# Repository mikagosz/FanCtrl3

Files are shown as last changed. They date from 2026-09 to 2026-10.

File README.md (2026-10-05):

<p align="center">
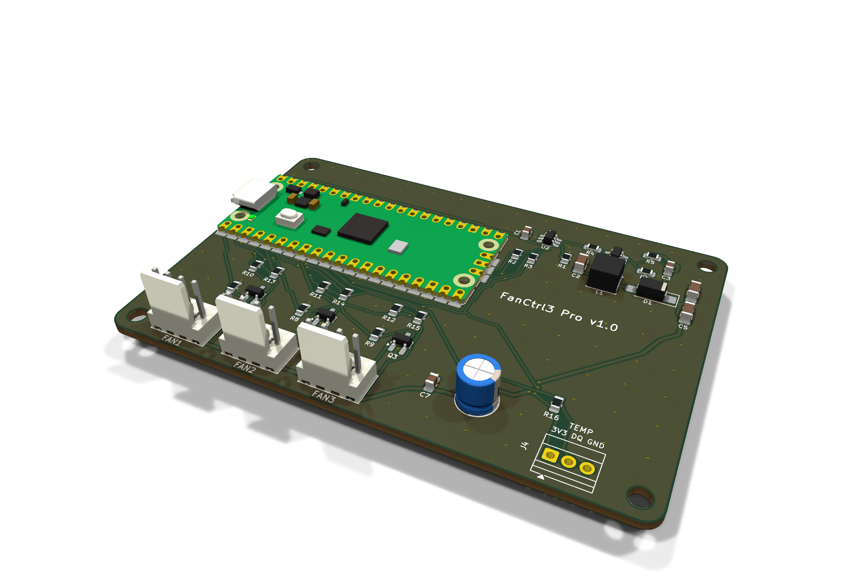
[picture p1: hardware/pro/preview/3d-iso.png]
FanCtrl3 Pro PCB, 3D render: Raspberry Pi Pico, three 4-pin fan headers, a temperature probe terminal and the on-board 12 V boost converter
  
</p>

## FanCtrl3

**A USB-powered controller for three 4-pin PWM fans, driven by the CPU temperature
of a Proxmox VE host.**

One USB cable to the host is all it needs — power, control and fan speed readings
all go over it. The fan curve runs **inside the controller**, so a host reboot, a
crashed service or a pulled cable never leaves the fans stopped.









Designed for small home servers and mini PCs running Proxmox: the machine sits in a
closed cabinet, its own fan is not enough for the cabinet, and a set of quiet 120 mm
fans should spin up only when the server actually works.

> [!NOTE]
> FanCtrl3 is a hobby project, built in spare time. Updates may not come often —
> but ideas, questions and build reports are always welcome (see
> [Contact and contributions](#contact-and-contributions)).

---

## Project status

> [!WARNING]
> **FanCtrl3 has not been tested on real hardware yet.** Hardware testing is coming
> soon; this section will be updated with the results. Until the first boards have
> run for a while, treat this as a reviewed design, not a proven product.

### Verified without hardware

| Area | How | Result |
|---|---|---|
| Schematics | KiCad ERC, both variants | 0 errors, 0 warnings |
| Pro PCB | KiCad DRC with schematic parity | 0 violations, 0 unconnected pads, 0 parity issues |
| Lite perfboard | the generator's own checker | every net connected, no hole shared by two nets, no wire through a foreign pad, no overlapping parts |
| Enclosure | intersection of the enclosure with the component bodies | 0 collisions, both variants |
| Control logic | 22 unit tests, run under CPython **and** MicroPython | all pass |
| Firmware `main.py` | runs under the MicroPython unix port on stubbed hardware: replies, 25 kHz inverted PWM, watchdog; `SERVICE` and service mode; `SAVE` success and failure (12 checks) | all pass |
| Host daemon and CLI | 10 unit tests (Intel and AMD sensors, several CPU packages, CLI errors, a silent socket client) and 13 end-to-end tests against a simulated controller: sensor selection, curve, `status`, `send`, `calibrate` (incl. a dead fan and failsafe), clean stop, restart without a temperature, crash → failsafe | all pass |

Every push and pull request runs these tests on GitHub Actions.

### Not tested yet

- Anything on a real board: soldering, the 12 V rail, the current limiter and its
  `FAULT` signal, real fan speeds from the tachometers, the DS18B20 probe, the LED,
  the watchdog, USB behaviour with and without a host.
- Power drawn from a real USB port with three fans at 100 %.
- The udev rule on a real Pico (`2e8a:0005` is MicroPython's default ID).
- Printing and fitting the enclosure; the Lite mounting-hole positions.

### Known issues

- AMD support (`k10temp`, `zenpower`) is tested only against simulated sensors so
  far — a report from a real AMD host is welcome.
- `tests/test_main_smoke.sh` depends on timing and can fail on a heavily loaded
  machine; run it again before looking for a bug.

## Features

- **Three 4-pin PWM fans**, 25 kHz PWM and tachometer reading on every channel.
- **Powered from USB only.** An on-board step-up makes the 12 V for the fans; a
  TI TPS2553 current-limited switch limits the fan side to 465–570 mA — the
  budget of a USB 2.0 port — and reports an overload to the controller.
- **Curve in the controller, temperature from the host.** A small daemon on the
  Proxmox host sends the CPU package temperature (Intel or AMD) every 5 seconds; the
  controller applies a curve with hysteresis and ramping.
- **Safe by default.** No temperature for 30 s → fans at 100 %. A dead
  microcontroller → the output transistors switch off → fans at 100 %. A clean host
  shutdown → fans rest at 20 % instead of alarming.
- **Ambient probe.** A DS18B20 on a cable measures the air in the cabinet and raises
  the fans on its own above 40 °C (60 %) and 45 °C (100 %).
- **Stall detection** per fan, per-fan minimum duty and a `calibrate` command that
  measures it.
- **Two variants, one firmware** — see below.
- **Host side needs nothing but Python 3's standard library**, a udev rule and a
  systemd unit.

## Two variants

| | **FanCtrl3 Lite** | **FanCtrl3 Pro** |
|---|---|---|
| Build | modules on a 72 × 47 mm perfboard (SCI PC-3) | custom 2-layer PCB, 90 × 60 mm |
| Soldering | through-hole only (plus one SOT-23-6 on an adapter) | 0805/1206 and SOT-23 by hand, no QFN |
| 12 V | Pololu U3V16F12 module | TI LM27313 boost on the board (12.4 V) |
| PWM output | BC547B, open collector | 2N7002, open drain |
| Current limit | TPS2553 on a SparkFun SOT-23 → DIP adapter | TPS2553 on the board |
| Pico | in sockets, removable | soldered flat |
| Build guide | [docs/build-lite.md](docs/build-lite.md) | [docs/build-pro.md](docs/build-pro.md) |

Both use the same pinout and run the same firmware.

<table>
  <tr>
    <td align="center">Lite perfboard drawing: component side and mirrored solder side with every wire<br><sub>Lite — perfboard wiring drawing</sub></td>
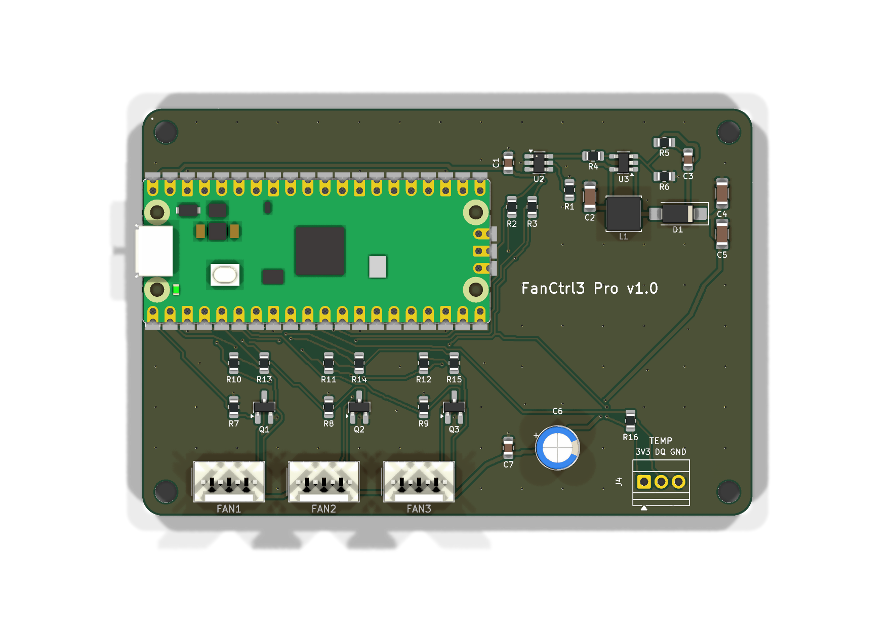
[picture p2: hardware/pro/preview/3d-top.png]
Pro PCB, 3D render from the top
    <td align="center"><br><sub>Pro — PCB, top</sub></td>
  </tr>
  <tr>
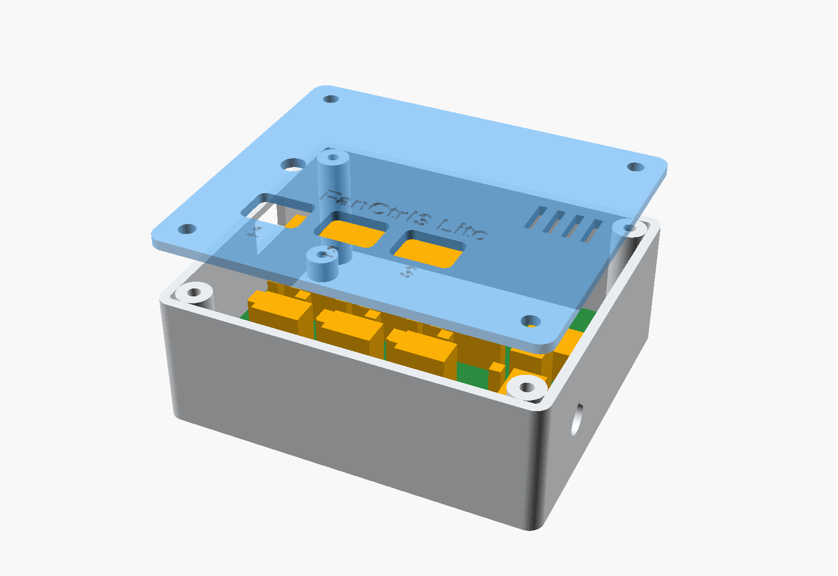
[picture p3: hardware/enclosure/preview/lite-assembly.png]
Lite enclosure with the board inside, preview
    <td align="center"><br><sub>Lite — enclosure</sub></td>
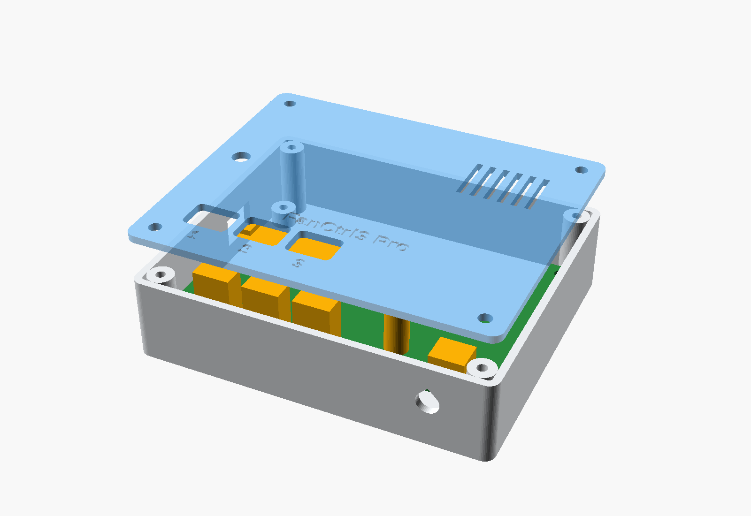
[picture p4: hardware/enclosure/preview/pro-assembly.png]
Pro enclosure with the board inside, preview
    <td align="center"><br><sub>Pro — enclosure</sub></td>
  </tr>
</table>

## How it works

```
 Proxmox host                                 FanCtrl3
┌────────────────────────┐   USB cable    ┌──────────────────────────────────────┐
│ CPU temp ─► fanctl     │  power + data  │ Pico: curve, hysteresis, failsafe    │
│             daemon ────┼───────────────►│  ├─ PWM ×3 ──► open collector/drain  │
│  TEMP 54.0 every 5 s   │◄───────────────│  ├─ tach ×3 ◄── fans                 │
│  STATUS, alarms        │                │  └─ DS18B20 ◄── ambient probe        │
└────────────────────────┘                │                                      │
                                          │ VBUS ─► TPS2553 ─► 12V boost ─► fans │
                                          │         (≈0.5 A)                     │
                                          └──────────────────────────────────────┘
```

The link is plain text over USB CDC — `TEMP 54.0`, `STATUS`, `SET 1 40` — so it can
be driven by hand from any terminal. Full protocol: [docs/firmware.md](docs/firmware.md).

## Power budget

The whole controller lives on one USB 2.0 port, which is allowed to supply
**500 mA**. The design is sized for three low-power 120 mm PWM fans rated at up
to **0.6 W each** (for example Noctua NF-P12 redux-1300 PWM):

3 × 0.6 W = 1.8 W at 12 V → ÷ 0.85 converter efficiency + ≈ 0.15 W for the Pico
≈ **0.45 A from the port**.

> [!CAUTION]
> Fans rated above 0.6 W each will not fit this budget. The TPS2553 limits the fan
> side to 465–570 mA and reports `FAULT`, but the fans will not reach full speed.
> Check the rated **input power** of your fans before you build.

## Getting started

1. **Pick a variant** and order the parts — [docs/bill-of-materials.md](docs/bill-of-materials.md).
2. **Build the board** — [Lite](docs/build-lite.md) or [Pro](docs/build-pro.md).
3. **Print the enclosure** — [docs/enclosure.md](docs/enclosure.md).
4. **Flash the firmware** — [docs/firmware.md](docs/firmware.md):
   MicroPython for `RPI_PICO`, then `firmware/flash.sh`.
5. **Install the host side on Proxmox** — [docs/host-proxmox.md](docs/host-proxmox.md):
   ```bash
   sh host/install.sh        # as root on the Proxmox host
   fanctl status
   fanctl calibrate          # finds the lowest duty each fan still spins at
   ```

## Repository layout

| Path | What is inside |
|---|---|
| [`hardware/tools/`](hardware/tools/) | generators — the design lives in code: [`design_pro.py`](hardware/tools/design_pro.py) and [`design_lite.py`](hardware/tools/design_lite.py) are the single source of truth |
| [`hardware/pro/`](hardware/pro/) | KiCad project of the Pro PCB, schematic PDF, [`fabrication/`](hardware/pro/fabrication/) Gerbers + drill ZIP and BOM, [`preview/`](hardware/pro/preview/) 3D renders |
| [`hardware/lite/`](hardware/lite/) | Lite schematic (KiCad + PDF), perfboard drawing (SVG) and wiring table |
| [`hardware/enclosure/`](hardware/enclosure/) | parametric OpenSCAD enclosure and ready STL files for both variants |
| [`firmware/`](firmware/) | MicroPython for the Pico: [`logic.py`](firmware/logic.py) (no hardware, testable) and [`main.py`](firmware/main.py) (pins) |
| [`host/`](host/) | `fanctl` daemon and CLI, udev rule, systemd unit, installer |
| [`sim/`](sim/) | the controller on a pseudo-terminal, for testing the host side without hardware |
| [`tests/`](tests/) | everything that runs without hardware: [`tests/run_all.sh`](tests/run_all.sh) |
| [`docs/`](docs/) | documentation |

## Documentation

- [Hardware design](docs/hardware.md) — circuit description, pinout, design decisions
- [Bill of materials](docs/bill-of-materials.md) — both variants, with suggested shop links
- [Building FanCtrl3 Lite](docs/build-lite.md) — perfboard assembly
- [Building FanCtrl3 Pro](docs/build-pro.md) — ordering the PCB and hand soldering
- [Enclosure](docs/enclosure.md) — printing and assembly
- [Firmware](docs/firmware.md) — flashing, control behaviour, serial protocol
- [Host software on Proxmox](docs/host-proxmox.md) — installation and `fanctl`
- [Development](docs/development.md) — regenerating the outputs, running the tests

## Contact and contributions

Ideas, improvements, a better circuit, a build report or a question — all welcome.
Open an issue on this repository or write to **support@fractal8.eu**. See
[CONTRIBUTING.md](CONTRIBUTING.md).

## Support the project

FanCtrl3 is built in spare time. If it is useful to you, you can support its
development through **[GitHub Sponsors](https://github.com/sponsors/mikagosz)** —
it helps pay for parts and prototype boards.

## Licence

MIT — see [LICENSE](LICENSE). This covers the hardware design files, the firmware
and the host software.

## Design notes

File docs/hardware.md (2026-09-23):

# Hardware design

FanCtrl3 comes in two variants built from the same circuit blocks: **Lite**
(ready-made modules on a perfboard) and **Pro** (everything on a custom PCB). They
share the pinout, so one firmware runs on both.

> [!NOTE]
> The hardware has not been tested yet — hardware testing is coming soon. The
> schematics pass ERC, the Pro PCB passes DRC and schematic parity, and the Lite
> perfboard layout passes its own connectivity check. See the
> [project status](../README.md#project-status).

Schematics: [Pro (PDF)](../hardware/pro/FanCtrl3-Pro-schematic.pdf) ·
[Lite (PDF)](../hardware/lite/FanCtrl3-Lite-schematic.pdf) — also as SVG in
[`docs/images/`](images/).

## Block diagram

```
USB VBUS (5 V) ──┬──────────────────────────────► Pico VBUS (the Pico makes its own 3.3 V)
                 │
                 └─► TPS2553 ─► +5V_FAN ─► 5 V → 12 V boost ─► +12V ─► fan headers J1–J3 (pin 2)
                     │    │
          FAULT → GP7    EN ← GP8 (pulled up: on by default)

Pico GP0/GP2/GP4 ─► NPN / N-MOSFET ─► fan PWM (pin 4, open collector / open drain)
Pico GP1/GP3/GP5 ◄── 10 kΩ ◄──┬── fan tach (pin 3)
                              └── 4.7 kΩ to 3.3 V
Pico GP6 ◄──► DS18B20 probe (1-Wire, 4.7 kΩ pull-up) on a 3-pole screw terminal
```

## Pinout (both variants)

| Pico pin | GPIO | Function |
|---|---|---|
| 1 | GP0 | fan 1 PWM |
| 2 | GP1 | fan 1 tach |
| 4 | GP2 | fan 2 PWM |
| 5 | GP3 | fan 2 tach |
| 6 | GP4 | fan 3 PWM |
| 7 | GP5 | fan 3 tach |
| 9 | GP6 | DS18B20 data (1-Wire) |
| 10 | GP7 | TPS2553 `FAULT` (open drain, active low, 10 kΩ pull-up) |
| 11 | GP8 | TPS2553 `EN` (active high, pulled up) |
| 36 | 3V3 | tach pull-ups, 1-Wire, limiter pull-ups |
| 40 | VBUS | 5 V from the host |
| — | GP25 | on-board LED: status |

Fan header (standard 4-pin PC fan, Molex KK 254): **1** GND · **2** +12 V ·
**3** tach · **4** PWM. The DS18B20 terminal: **1** 3.3 V (red) · **2** DQ (yellow) ·
**3** GND (black).

## Power

### Budget

The controller takes everything from one USB port. A USB 2.0 device — the Pico is
one — may draw **500 mA**. FanCtrl3 is sized for three fans of up to **0.6 W** each:

| | |
|---|---|
| Fans at 100 % | 3 × 0.6 W = 1.8 W at 12 V |
| From 5 V, 85 % converter efficiency | ≈ 2.1 W |
| Pico | ≈ 0.15 W |
| **Total from the port** | **≈ 0.45 A** |

Heavier fans do not fit: the current limiter will hold the fan side at its limit
and report `FAULT`, and the fans will not reach full speed.

### Current limiter — TPS2553

The fan side sits behind a **TI TPS2553** current-limited power switch. The Pico
itself stays on raw VBUS, so it keeps running and can report the problem when the
fans are shorted or overloaded.

- **RILIM = 51 kΩ** → current limit **465–570 mA** (TI datasheet, equation 1).
- **`FAULT`** (open drain, 10 kΩ pull-up to 3.3 V) goes to GP7. The firmware reports
  `ALARM FAULT` / `INFO FAULT OK`. The TPS2553 filters short events such as inrush
  at start-up.
- **`EN`** (active high) is pulled up to 3.3 V, so the fans are powered even
  before the firmware runs and when the Pico is dead. GP8 drives it high.
- 100 nF at the `IN` pin.

On **Pro** the TPS2553 is on the board (SOT-23-6). On **Lite** it sits on a
**SparkFun BOB-00717** SOT-23 → DIP-6 adapter (8.6 × 11.7 mm, rows 7.62 mm apart),
together with C3 and the flat-mounted resistors R14–R16, **under** the Pico — the Pico
stands 11 mm above the perfboard in its sockets and the adapter is about 6 mm tall.

### 12 V

| | Lite | Pro |
|---|---|---|
| Converter | **Pololu U3V16F12** module, fixed 12 V ± 4 % | **TI LM27313** boost, SOT-23-5 |
| Output | 12 V | 12.4 V (divider 91 kΩ / 10 kΩ: 1.23 V × (1 + 91/10)) |
| Parts | 47 µF at the module input (Pololu recommends ≥ 33 µF), 100 µF on the 12 V rail | 10 µH inductor, SS14 Schottky diode, 220 pF feed-forward across the top divider resistor, 2 × 10 µF + 100 µF + 100 nF on the output, 10 µF at the input; `SHDN` pulled up (51 kΩ) |
| Basis | module datasheet | TI's typical 5 V → 12 V / 250 mA application |

A fixed output was chosen on purpose: no trimmer that could drift or be set wrong.
12.4 V is within the normal tolerance of 12 V fans.

## Fan channels

### PWM output

4-pin fans pull their PWM input up internally and expect an **open-collector /
open-drain** driver at **25 kHz**. Pulling the line low slows the fan down.

| | Lite | Pro |
|---|---|---|
| Transistor | BC547B (NPN, TO-92) | 2N7002 (N-MOSFET, SOT-23) |
| Drive | GPIO → 4.7 kΩ → base, 10 kΩ base to GND | GPIO → gate, 100 kΩ gate to GND |

Because the transistor pulls the line low, the logic is **inverted**: GPIO high →
transistor on → fan slower. The firmware takes care of it.

**Fail-safe by construction:** when the Pico is dead, unplugged from its socket or
still booting, the pull-down resistor keeps the transistor off, the fan pulls its
own PWM line high, and the fan runs at **100 %**. The same applies at power-up —
all three fans start at full speed until the firmware takes over.

A BC547 is used on Lite rather than a 2N7000 because a 2N7000 is only marginally
on with 3.3 V at the gate.

### Tachometer

The fan's tach output is an open collector, 2 pulses per revolution. It is pulled
up to **3.3 V with 4.7 kΩ on the fan side** and then goes through **10 kΩ in
series** to the GPIO. The series resistor protects the Pico if a fan (or a wrong
cable) drives the tach line to 12 V. The order matters: with the 10 kΩ first and
the pull-up at the GPIO, the low level would not go below about 2.2 V.

## Ambient temperature

A **DS18B20 probe on a cable** (waterproof version) sticks out of the enclosure
and measures the air in the cabinet, not the heat of the board. It connects to a
3-pole screw terminal — no crimping. 4.7 kΩ pull-up on DQ.

The controller uses it on its own, whatever the host says: from **40 °C** the fans
run at least **60 %**, from **45 °C** at **100 %**.

## Layout notes

### Pro PCB

- 2 layers, 90 × 60 mm, 1.6 mm, four M3 mounting holes in the corners.
- Smallest track 0.25 mm, vias 0.3/0.6 mm, smallest hole 0.3 mm — standard
  capabilities of common low-cost PCB fabs.
- Hand-solderable footprints only: 0805/1206 with "HandSolder" pads, SOT-23, SMA,
  no parts with pads underneath.
- The Pico is soldered flat by its castellated edge; its micro-USB socket overhangs
  the board edge by about 1 mm for the enclosure opening.
- Ground pour on both layers. Power tracks (VBUS, the limited 5 V, the converter
  switch node and 12 V) are 0.4–0.6 mm wide, signals 0.25 mm.

### Lite perfboard

- SCI PC-3: 25 × 15 holes on 2.54 mm, 72 × 47 mm, single-sided, the four corner
  positions are mounting holes (371 holes).
- The Pico sits in two 20-pin sockets along rows B and I, USB to the left. Fan
  headers along the bottom edge, at least 15.24 mm apart so the lid openings do not
  merge. The probe terminal and the Pololu module are on the right.
- Ground is a bare rail along row O. Everything else is bare wire on the solder
  side, plus 15 insulated wires where a bare route would be too long or impossible
  (3.3 V and 12 V are always insulated).
- The layout, the wiring and the checks are generated — see
  [development.md](development.md).
- Wiring table: [`hardware/lite/FanCtrl3-Lite-wiring.md`](../hardware/lite/FanCtrl3-Lite-wiring.md).

## Known limitations

- **Not tested on hardware yet.** Footprints of the Molex header and the screw
  terminal were checked against drawings; the SparkFun adapter dimensions come from
  the SparkFun product page; nothing has been built yet.
- The fans start at 100 % when USB is plugged in, before the firmware runs. That
  is intentional (fail-safe) and stays within the current limit, but it is audible.
- Only fans up to about 0.6 W each fit the USB power budget.

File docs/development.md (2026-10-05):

# Development

The hardware of FanCtrl3 is **generated from code**. Each variant has one design
file that is the single source of truth; KiCad files, the perfboard drawing, the
wiring table, the enclosure geometry and the fabrication outputs are all derived
from it. Edit the design file, run the build script, commit the results.

## Tools

| Tool | Version used | Needed for |
|---|---|---|
| Python | 3.9 or newer (developed on 3.14) | generators, host daemon, tests |
| KiCad | 10 | schematics, PCB, ERC/DRC, Gerbers, renders |
| OpenSCAD | 2024 or newer, Manifold backend (developed on 2026.06) | enclosure |
| MicroPython (unix port) | 1.2x (developed on 1.29) | running the firmware tests |
| mpremote | any recent | copying the firmware to the Pico |
| bash | 3.2 or newer (macOS's built-in one is enough) | the build and test scripts (`*.sh`, except `host/install.sh`, which is POSIX sh) |

The scripts use the default macOS install location of KiCad. Elsewhere, point them
at your install:

```bash
export KICAD_CLI=/usr/bin/kicad-cli
export KICAD_PYTHON=/usr/bin/python3          # a Python that can `import pcbnew`
export KICAD_SHARE=/usr/share/kicad           # holds symbols/ and footprints/
```

## Hardware

### Pro — `hardware/tools/design_pro.py`

```bash
hardware/tools/build_pro.sh    # schematic -> ERC -> place -> geom -> route -> finish -> DRC
hardware/tools/export_pro.sh   # Gerbers + drill -> ZIP, BOM CSV, schematic PDF
```

- `gen_sch.py` writes the schematic: every pin gets a short stub with a net label or
  power symbol, so every connection is explicit.
- `gen_pcb.py place` places the footprints and the silkscreen (inside KiCad's
  Python), `gen_pcb.py geom` exports the pad geometry, `router.py` routes the tracks,
  and `gen_pcb.py finish` adds them to the board with GND stitching vias and fills
  the ground zones.
- DRC runs with `--schematic-parity`: the board has to match the schematic.
- The router is not deterministic — each run gives slightly different tracks, each
  passing DRC. **Run `export_pro.sh` right after every `build_pro.sh`.**

### Lite — `hardware/tools/design_lite.py`

```bash
hardware/tools/build_lite.sh   # layout search + routing + checks, SVG, wiring table, enclosure geometry, schematic, ERC, PDF
```

`gen_lite.py` tries every combination of fan-channel columns and limiter
positions (280 placements), routes each with a few random net orders, then gives
the five best many more orders. Bare wire runs hole to hole on the solder side and
never shares a hole with another net; what cannot be routed that way within a
detour limit becomes an insulated wire. The layout with the fewest signal wires,
then the shortest insulated wire, wins. A full run takes about two minutes and
gives the same result every time.

The checker rejects a layout if any net is not connected, a hole carries two nets,
a wire passes a foreign pad, a part sticks out of the board, part bodies overlap,
or a part under the Pico covers its sockets.

Environment variables for quick experiments: `LITE_TRIES_FIRST` (default 20),
`LITE_KEEP` (5), `LITE_TRIES` (120).

Translations: when a file `<lang>/lang_<lang>.py` exists at the repository root,
`build_lite.sh` also writes the drawing and the wiring table in that language into
the same folder. Such local folders are not tracked.

### Enclosure

```bash
hardware/tools/build_enclosure.sh   # 4 STL files, collision check, previews
```

Run `build_lite.sh` first when the Lite layout changed — it writes
`hardware/enclosure/FanCtrl3-lite-geometry.scad`, which the enclosure reads.

## Firmware and host

```bash
tests/run_all.sh
```

| Test | What it covers |
|---|---|
| `tests/test_logic.py` | the control logic, under CPython **and** MicroPython (same file, plain asserts): curve, hysteresis, ramps, stale temperature, BYE/rest, minimum duty, ambient override, stall alarm, FAULT edge, manual mode, protocol errors, config merge |
| `tests/test_main_smoke.sh` | the real `firmware/main.py` under the MicroPython unix port with a stub `machine` module ([`tests/stubs/machine.py`](../tests/stubs/machine.py)): replies to commands, 25 kHz PWM, inverted output, 8 s watchdog |
| `tests/test_e2e.py` | host daemon + CLI against [`sim/pico_sim.py`](../sim/pico_sim.py), a simulated controller on a pseudo-terminal with pretend fans: waiting for the device, picking the right hwmon sensor, curve, `status`, `send`, `calibrate`, clean stop → rest, crash → failsafe |

The simulator is also handy on its own for trying the host side:

```bash
python3 sim/pico_sim.py --link /tmp/fanctl
fanctl --device /tmp/fanctl status
```

## Conventions

- One design file per variant; generated files are committed so that people can
  use them without running anything, but never edited by hand.
- Firmware logic without hardware in `logic.py`, pins and timers in `main.py` —
  everything that can be tested off the board lives in `logic.py`.
- The host side uses the Python standard library only.

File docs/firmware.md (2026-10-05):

# FanCtrl3 firmware

FanCtrl3 drives three 4-pin PWM fans from a Raspberry Pi Pico running MicroPython.
The controller is powered over USB and runs the fan curve itself. The host only reports
the CPU temperature over the same USB cable (see [host-proxmox.md](host-proxmox.md)).

> [!NOTE]
> **Status:** the hardware has not been tested yet. The firmware logic and the host daemon
> pass automated tests against a simulator. Hardware testing is coming soon.

## Contents

- [Firmware files](#firmware-files)
- [Installing MicroPython](#installing-micropython)
- [Copying the firmware](#copying-the-firmware)
- [Service access](#service-access)
- [Pinout](#pinout)
- [Control behaviour](#control-behaviour)
- [Serial protocol](#serial-protocol)
- [The STAT line](#the-stat-line)
- [Unsolicited messages](#unsolicited-messages)
- [Configuration and persistence](#configuration-and-persistence)
- [Status LED](#status-led)
- [Watchdog and error handling](#watchdog-and-error-handling)
- [Simulator and tests](#simulator-and-tests)

## Firmware files

| File | Purpose |
|---|---|
| [`firmware/logic.py`](../firmware/logic.py) | All control decisions: modes, fan curve, hysteresis, ramps, alarms, the command protocol and the configuration defaults. It does not access any hardware and runs under both MicroPython and CPython. |
| [`firmware/main.py`](../firmware/main.py) | Hardware layer for the Pico (MicroPython `rp2` port): PWM outputs, tachometer inputs, DS18B20 ambient probe, power-switch fault input, LED, watchdog, USB serial I/O and the configuration file. |
| [`firmware/flash.sh`](../firmware/flash.sh) | Copies `logic.py` and `main.py` onto a Pico that already runs MicroPython. |

The firmware version is `VERSION` in `logic.py`; `VER` reports it. It follows the project version in [CHANGELOG.md](../CHANGELOG.md).

## Installing MicroPython

The firmware needs the standard MicroPython build for the Raspberry Pi Pico.

1. Download the MicroPython UF2 file for the **`RPI_PICO`** board from micropython.org.
2. Hold down the **BOOTSEL** button on the Pico and connect it to your computer over USB.
   Release the button once it is connected.
3. The Pico appears as a USB drive. Copy the UF2 file onto it. The Pico reboots into
   MicroPython when the copy completes.

## Copying the firmware

[`firmware/flash.sh`](../firmware/flash.sh) uses `mpremote` to copy the two firmware files
to the root of the Pico's filesystem and reset the board. It runs the following command
from the `firmware/` directory:

```sh
mpremote connect auto cp logic.py :logic.py + cp main.py :main.py + reset
```

Requirements on the computer used for flashing:

- `mpremote`, installed with `pipx install mpremote` (or `pip install --user mpremote`).
- `bash`, which `flash.sh` runs in (on macOS the built-in one is enough).

To flash a Pico that runs a fresh MicroPython install, connect it and run:

```sh
./firmware/flash.sh
```

After the reset, `main.py` starts automatically and the controller begins in **start** mode.

To update a controller that is already running FanCtrl3, you must first get past its
Ctrl-C protection. See [Service access](#service-access).

> [!IMPORTANT]
> If the controller is connected to a host running the `fanctl` daemon, stop the daemon
> first (`systemctl stop fanctl`). The daemon holds the serial port open. Stopping it
> sends `BYE`, so the controller switches to rest duty.

## Service access

After the service window closes, the firmware ignores Ctrl-C (`micropython.kbd_intr(-1)`).
Without this protection, one stray byte on the serial line could stop the program and
leave the fans without control. You can reach the MicroPython REPL (and therefore
`mpremote`) in two ways:

| Method | How it works |
|---|---|
| **Service window** | For the first **3000 ms** after power-up (`SERVICE_WINDOW_MS`), Ctrl-C still works. During this window the firmware prints the banner `FanCtrl3 <version> start` and waits. The fans run at the start duty. The control loop and the watchdog have not started yet, and commands are not processed. Run `flash.sh` (or any `mpremote` command) right after you connect or reset the board. |
| **`SERVICE` command** | The controller replies `OK SERVICE`, sets all three fans to 100 %, prints `SERVICE: resetting into service mode`, leaves a flag file (`fanctrl3.service`) and resets. The next boot finds the flag, removes it, keeps the fans at 100 %, prints `FanCtrl3 <version> service mode: REPL, fans at 100%, reset to resume` and stays at the MicroPython REPL — **without starting the watchdog**. Send it with `fanctl send SERVICE` from the host. |

The reset is deliberate: the RP2040 watchdog cannot be stopped once it runs, so the
firmware never drops to the REPL from the running control loop. Service mode lasts
until the next reset or power-cycle; `flash.sh` resets the board when it finishes, and
the board then starts normally.

## Pinout

The pinout is the same on the Pro and Lite boards.

| Pico pin | Direction | Function |
|---|---|---|
| GP0 | Output | Fan 1 PWM |
| GP1 | Input, pull-up | Fan 1 tachometer |
| GP2 | Output | Fan 2 PWM |
| GP3 | Input, pull-up | Fan 2 tachometer |
| GP4 | Output | Fan 3 PWM |
| GP5 | Input, pull-up | Fan 3 tachometer |
| GP6 | 1-Wire | DS18B20 ambient temperature probe |
| GP7 | Input, pull-up | TPS2553 `FAULT`, active low (on the Lite board the TPS2553 sits on an adapter) |
| GP8 | Output, driven high | TPS2553 `EN`. Driven high so the fans are powered; the board also pulls it up. |
| `LED` | Output | On-board status LED |

**PWM outputs.** The PWM frequency is 25 kHz. Each output drives an open-collector /
open-drain stage, so the logic is inverted: a high pin turns the transistor on, pulls the
fan's PWM line low and slows the fan. The firmware writes
`duty_u16 = (100 − duty%) × 65535 / 100`. At initialisation every pin is low (transistor
off), so the fans run at full speed until the controller applies the start duty.

**Tachometer inputs.** The firmware counts falling edges in interrupt handlers and
converts them to rpm once per control step, assuming **2 pulses per revolution**:
`rpm = pulses × 60 / 2 / elapsed seconds`.

**Ambient probe.** The DS18B20 is read without blocking. The firmware starts a conversion
and reads the result on a later pass, at least 800 ms after the start. It uses the first
sensor found on the bus. If no sensor is found, it scans again every 30 s. It discards
readings outside the range −40 to 85 °C (both limits excluded), because 85.0 °C is the
sensor's power-on value and not a real reading. After a bus error the firmware clears
the reading and scans for the sensor again. With no working probe, the ambient value is
reported as `-`. Ambient protection is then inactive and no alarm is raised.

## Control behaviour

The control step runs once per second. Duty values are percentages of fan speed
(100 = full speed).

### Modes

At every step the controller selects one mode. The conditions below are checked in
order, and the first one that applies wins.

| Mode | Condition | Base duty |
|---|---|---|
| `rest` | `BYE` received, and no `TEMP` or `HELLO` since | `rest_duty` = **20 %** |
| `failsafe` | No `TEMP` for more than `stale_s` = **30 s** (counted from power-up if no `TEMP` has ever arrived) | **100 %**, applied immediately with no ramp |
| `start` | Power-up, before the first `TEMP` | `start_duty` = **60 %** |
| `auto` | A recent `TEMP` is available | Fan curve, with hysteresis |

Notes:

- The controller stays in `start` mode for at most 30 s. If no `TEMP` arrives by then,
  it switches to `failsafe`.
- `rest` has no timeout. It lasts until the next `TEMP` or `HELLO` arrives and does not
  turn into `failsafe`. Use `BYE` for a planned host shutdown.
- `HELLO` (sent by the host daemon every time it connects) leaves `rest`, forgets the
  last CPU temperature and restarts the stale timer: the controller is in `start` and
  goes to `failsafe` unless a `TEMP` arrives within `stale_s`.
- A valid `TEMP` switches the reported mode to `auto`, and `BYE` to `rest`, at once.
  The fans follow at the next control step.

### Fan curve

The default curve maps the CPU temperature (°C) to a duty (%):

| CPU temperature | Duty |
|---|---|
| 35 °C | 20 % |
| 50 °C | 35 % |
| 65 °C | 60 % |
| 75 °C | 100 % |

- Between two points, the duty is interpolated linearly.
- At or below the first point, the duty equals the first point's duty.
- Above the last point, the duty is **100 %**, whatever duty the last point specifies.

### Hysteresis

`hyst` = **3.0 °C**. The curve is evaluated at an *effective* temperature:

- When the CPU temperature rises above the effective temperature, the effective
  temperature follows it immediately.
- When the CPU temperature falls, the effective temperature stays where it is until the
  CPU is more than 3.0 °C below it. After that it follows the CPU temperature 3.0 °C
  above it.

This stops the fans from speeding up and slowing down every second.

### Target duty for each fan

Each fan's target is calculated every step, in this order:

1. The mode's base duty. If the fan is under manual control (`SET n <duty>`), the manual
   value replaces the base duty.
2. At least the fan's `min_duty` (default **20 %** for each fan). This floor also applies
   to manual values.
3. If the ambient temperature is at or above `amb_warn` = **40.0 °C**, at least
   `amb_warn_duty` = **60 %**.
4. In `failsafe` mode, or if the ambient temperature is at or above `amb_crit` =
   **45.0 °C**: **100 %**.
5. The result is limited to 0–100 %.

The ambient levels have a hysteresis of `amb_hyst` = **1.0 °C**: a level is entered at
its threshold and left only when the temperature falls more than 1.0 °C below it
(below 39.0 °C for the warning level, below 44.0 °C for the critical one). A probe
reading that hovers around a threshold therefore does not make the fans or the alarms
flap.

Manual control therefore never overrides the safety rules in steps 2–4.

### Ramps

The output duty moves toward the target at a limited rate:

| Parameter | Default |
|---|---|
| `ramp_up` | **10 % per second** |
| `ramp_down` | **2 % per second** |

When the target is 100 % because of `failsafe` or critical ambient temperature, the
controller applies it immediately, without a ramp.

### Stall detection

A fan is reported as stalled when all of the following are true:

- the fan header is enabled (`ENABLE n 1`, the default), and
- the fan's actual output duty is at least `stall_duty` = **30 %**, and
- the fan reports **0 rpm** for `stall_s` = **5 s** in a row.

The controller then sends `ALARM FANn STALL`. It sends `INFO FANn OK` when the condition
clears. A stall is reported only; it does not change the duty. Disabled headers never
raise stall alarms, and disabling a header does not switch its PWM output off.

### Power-switch fault

When the TPS2553 `FAULT` input (GP7) is low, the controller sends `ALARM FAULT`. It sends
`INFO FAULT OK` when the input goes high again. The fault is reported only: the `EN`
output stays high and the duty does not change.

## Serial protocol

The controller communicates over USB CDC serial, one text line per command.

- A line ends with LF or CR.
- The command word is not case-sensitive. Arguments are separated by spaces.
- Fan numbers are `1`, `2` or `3`.
- Lines longer than 120 characters are truncated. Empty lines are ignored.
- The controller processes commands only after the [service window](#service-access)
  has closed.

### Commands

| Command | Arguments | Reply | Effect |
|---|---|---|---|
| `PING` | – | `PONG` | Connection test. |
| `VER` | – | `VER FanCtrl3 <version>` | Firmware version. |
| `TEMP <t>` | CPU temperature in °C, −20 to 130 | `OK` | Stores the CPU temperature, resets the stale timer, leaves `rest` and sets the mode to `auto`. |
| `BYE` | – | `OK REST` | Planned host shutdown: `rest` mode (20 %) until the next `TEMP` or `HELLO`. |
| `HELLO` | – | `OK HELLO` | A host daemon connected: leaves `rest`, clears the CPU temperature and restarts the stale timer (`start` mode, then `failsafe` if no `TEMP` follows). |
| `STATUS` or `STAT` | – | `STAT …` | Current state. See [The STAT line](#the-stat-line). |
| `SET <n> <duty>` | fan, duty 0–100 | `OK` | Puts fan *n* under manual control at the given duty. Out-of-range values are clamped to 0–100. |
| `SET <n> AUTO` | fan | `OK` | Returns fan *n* to automatic control. |
| `AUTO` | – | `OK` | Returns all fans to automatic control. |
| `MIN <n> <duty>` | fan, duty 0–100 | `OK` | Sets the minimum duty of fan *n*, clamped to 0–100 and truncated to an integer. |
| `ENABLE <n> <v>` | fan, `1` / `on` / `ON` | `OK` | Enables stall detection for fan *n* when *v* is `1`, `on` or `ON`. Any other value disables it. |
| `CURVE <t:d> <t:d> …` | two or more points | `OK` | Replaces the fan curve. Each point is `temperature:duty`. |
| `SAVE` | – | `OK SAVE` or `ERR SAVE <reason>` | Writes the current configuration to the Pico's filesystem; replies once the write is done. |
| `CONF` | – | `CONF {…}` | Current configuration as JSON on a single line. |
| `SERVICE` | – | `OK SERVICE` | Resets the board into service mode. See [Service access](#service-access). |

Changes made with `SET`, `MIN`, `ENABLE` and `CURVE` take effect immediately. Only
`MIN`, `ENABLE` and `CURVE` are part of the configuration that `SAVE` stores. Manual
`SET` values are never saved, so after a reset all fans are under automatic control.

### Error replies

| Reply | Cause |
|---|---|
| `ERR ARGS <CMD>` | A required argument is missing or cannot be parsed (`nan` and `inf` count as unparseable), or the fan number is not 1–3. `<CMD>` is the command word in upper case. |
| `ERR UNKNOWN <CMD>` | Unknown command. |
| `ERR SAVE <reason>` | `SAVE` could not write the configuration file. |
| `ERR TEMP out of range` | `TEMP` value outside −20 to 130 °C. The value is ignored. |
| `ERR CURVE need at least 2 points` | `CURVE` with fewer than two points. |
| `ERR CURVE temperatures must rise` | The point temperatures are not strictly increasing. |
| `ERR CURVE duty must be 0..100` | A point's duty is outside 0–100. |

When `CURVE` is rejected, the existing curve stays in place.

### Examples

```text
> TEMP 54.0
< OK
> SET 2 40
< OK
> CURVE 30:20 45:35 60:60 70:100
< OK
> MIN 4 20
< ERR ARGS MIN
> CURVE 50:40 40:60
< ERR CURVE temperatures must rise
> SAVE
< OK SAVE
```

## The STAT line

Example:

```text
STAT mode=auto cpu=54.0 age=3 amb=27.5 fault=0 f1=54/728 f2=54m/728 f3=54/728
```

| Field | Meaning |
|---|---|
| `mode` | `start`, `auto`, `rest` or `failsafe`. Updated at each control step, except that a valid `TEMP` switches it to `auto` and `BYE` to `rest` at once. |
| `cpu` | Last CPU temperature received with `TEMP`, one decimal place. `-` if none has been received. |
| `age` | Whole seconds since the last `TEMP`. `-` if none has been received. |
| `amb` | Ambient temperature from the DS18B20, one decimal place. `-` if there is no valid reading. |
| `fault` | `1` while the TPS2553 `FAULT` input is active, otherwise `0`. |
| `f1`, `f2`, `f3` | `<duty>[m]/<rpm>` for each fan. `duty` is the current output duty in %, rounded to an integer. A trailing `m` means the fan is under manual control (`SET`). `rpm` is the speed measured during the last control step. |

## Unsolicited messages

The controller sends these lines without being asked:

| Message | When |
|---|---|
| `FanCtrl3 <version> start` | At power-up, at the start of the service window. |
| `ALARM TEMP STALE` / `INFO TEMP OK` | Entering / leaving `failsafe`. |
| `ALARM AMB HIGH` | Ambient temperature rises into the warning level (≥ 40.0 °C). |
| `ALARM AMB CRIT` | Ambient temperature rises into the critical level (≥ 45.0 °C). |
| `INFO AMB HIGH` | Ambient temperature falls from the critical level back to the warning level. |
| `INFO AMB OK` | Ambient temperature falls back to normal, or the probe stops giving readings. |
| `ALARM FAULT` / `INFO FAULT OK` | TPS2553 fault input becomes active / inactive. |
| `ALARM FANn STALL` / `INFO FANn OK` | Fan *n* stalls / recovers (see [Stall detection](#stall-detection)). |
| `ERR INTERNAL <error>` | An exception occurred in the main loop (see [Watchdog and error handling](#watchdog-and-error-handling)). |
| `SERVICE: resetting into service mode` | After `SERVICE`, just before the reset. |
| `FanCtrl3 <version> service mode: REPL, fans at 100%, reset to resume` | At the boot after `SERVICE`. |

Each alarm is reported once when the condition starts, and once more (as `INFO`) when
it ends. The ambient messages report every change of level, one line per change.

## Configuration and persistence

The configuration is stored as JSON in **`/fanctrl3.json`** at the root of the Pico's
filesystem.

**At power-up** the controller starts from the defaults below and applies the saved file
over them:

- If the file is missing or cannot be read, the defaults are used.
- Unknown keys are ignored.
- A value of the wrong type is ignored, and the default is kept. An integer is accepted
  where the default is a floating-point number.
- `min_duty` and `enabled` must be lists of exactly three numbers; otherwise the
  default is kept.
- If the saved curve is invalid, the default curve is used.

**`SAVE`** writes the complete current configuration, including every key, to
`/fanctrl3.json.tmp` and then renames it to `/fanctrl3.json`. The reply comes after the
write: `OK SAVE` when the file is written, `ERR SAVE <reason>` when it is not (the
configuration in memory stays as it is; send `SAVE` again). Changes made with `CURVE`, `MIN` and
`ENABLE` are lost at the next reset unless you save them.

**`CONF`** returns the configuration currently in memory. It may differ from the saved
file if you have not saved your changes yet.

### Defaults

| Key | Default | Meaning | Protocol command |
|---|---|---|---|
| `curve` | `[[35, 20], [50, 35], [65, 60], [75, 100]]` | CPU °C → duty % | `CURVE` |
| `min_duty` | `[20, 20, 20]` | Minimum duty for each fan, % (measure with `fanctl calibrate`) | `MIN` |
| `enabled` | `[1, 1, 1]` | 0 = no fan on that header (no stall alarms) | `ENABLE` |
| `hyst` | `3.0` | °C the CPU must fall before the fans slow down | – |
| `ramp_up` | `10.0` | % per second | – |
| `ramp_down` | `2.0` | % per second | – |
| `stale_s` | `30` | Seconds without `TEMP` before `failsafe` | – |
| `start_duty` | `60` | Duty after power-up, before the first `TEMP` | – |
| `rest_duty` | `20` | Duty after `BYE` | – |
| `amb_warn` | `40.0` | Ambient °C at which the duty is at least `amb_warn_duty` | – |
| `amb_warn_duty` | `60` | % | – |
| `amb_crit` | `45.0` | Ambient °C at which the duty is 100 % | – |
| `amb_hyst` | `1.0` | °C below a threshold before its ambient level clears | – |
| `stall_duty` | `30` | Stall check applies at or above this duty, % | – |
| `stall_s` | `5` | Seconds at 0 rpm before `ALARM FANn STALL` | – |

Keys without a protocol command can only be changed in the file. Enter the service
window, copy the file off the Pico, edit it, copy it back and reset the board:

```sh
mpremote connect auto cp :fanctrl3.json fanctrl3.json
# edit fanctrl3.json
mpremote connect auto cp fanctrl3.json :fanctrl3.json + reset
```

If the file does not exist yet, run `fanctl send SAVE` once to create it with the
current values.

## Status LED

The on-board LED shows the current mode. Each pattern repeats every 2 s, except in
`failsafe`.

| Mode | Pattern |
|---|---|
| `auto` | One short flash (60 ms) every 2 s |
| `start`, `rest` | Two short flashes (60 ms each, 200 ms apart) every 2 s |
| `failsafe` | Fast blinking: 125 ms on, 125 ms off |

The LED stays off during the service window.

## Watchdog and error handling

- **Hardware watchdog.** The firmware starts a watchdog with an **8000 ms** timeout when
  the service window closes, and feeds it on every pass of the main loop. If the loop
  hangs, the board resets and starts again in `start` mode.
- **Non-blocking loop.** The firmware polls the serial input with a 20 ms timeout,
  counts tachometer pulses in interrupts and reads the DS18B20 without waiting. The
  control step runs once per second.
- **Exceptions.** An exception inside the main loop never stops the loop. The firmware
  sends `ERR INTERNAL <error>`, sets all fans to 100 % and continues. The next
  successful control step applies the normal duty again.
- **Clock.** The firmware keeps an internal millisecond counter that does not wrap
  around, so timeouts behave the same however long the controller runs.

## Simulator and tests

You can test the control logic and the host software without hardware.

**Simulator.** [`sim/pico_sim.py`](../sim/pico_sim.py) runs the real `firmware/logic.py`
on a pseudo-terminal. It prints the device path, then behaves like the controller: it
reads and writes text lines and runs a control step every second. In the simulator, a
fan turns at 1300 rpm × duty and stops below 18 % duty.

```sh
python3 sim/pico_sim.py [--stale S] [--link PATH] [--state FILE] [--dead N] [--amb T]
```

| Option | Effect |
|---|---|
| `--stale S` | Overrides `stale_s`. |
| `--link PATH` | Creates a symlink to the pseudo-terminal. |
| `--state FILE` | Rewrites the state as JSON every step. |
| `--dead N` | Fan *N* never turns. The option can be repeated. |
| `--amb T` | Simulated ambient temperature. |

To point the host tool at the simulator, pass the link as its device, for example
`host/fanctl --device PATH status`.

**Tests.** [`tests/run_all.sh`](../tests/run_all.sh) runs every test that does not need
hardware. It needs `bash`, `python3` and the unix port of MicroPython (`micropython`,
on Debian and Ubuntu `apt install micropython`). The same script runs on GitHub Actions
for every push and pull request.

| Test | What it covers |
|---|---|
| `python3 tests/test_logic.py` | Control logic under CPython |
| `micropython tests/test_logic.py` | The same tests under MicroPython |
| `tests/test_main_smoke.sh` | Runs `firmware/main.py` under unix MicroPython with a stub `machine` module ([`tests/stubs/machine.py`](../tests/stubs/machine.py)) |
| `python3 tests/test_host.py` | `fanctl` without a controller: CPU sensor discovery (Intel, AMD, several packages), CLI error messages, the daemon's socket |
| `python3 tests/test_e2e.py` | End-to-end test: simulator, `fanctl` daemon and `fanctl` commands. Takes about a minute. |

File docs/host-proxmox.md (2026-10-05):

# FanCtrl3 on a Proxmox VE host

This document covers the host side of FanCtrl3: the `fanctl` tool and daemon, its udev
rule and its systemd service. For the controller firmware and the full serial protocol,
see [firmware.md](firmware.md).

> [!NOTE]
> **Status:** the hardware has not been tested yet. The firmware logic and the host daemon
> pass automated tests against a simulator. Hardware testing is coming soon.

## Contents

- [How it works](#how-it-works)
- [Requirements](#requirements)
- [Installation](#installation)
- [Installed files](#installed-files)
- [The fanctl command](#the-fanctl-command)
- [Calibrating the minimum duty](#calibrating-the-minimum-duty)
- [Troubleshooting](#troubleshooting)
- [Uninstalling](#uninstalling)

## How it works

The host runs one small service, `fanctl daemon` ([`host/fanctl`](../host/fanctl)). Every
5 seconds it:

1. reads the CPU package temperature from the kernel's hwmon interface,
2. sends it to the controller as `TEMP <t>`,
3. requests `STATUS` and keeps the reply for `fanctl status`.

**The fan curve runs in the controller, not on the host.** The host only supplies the
CPU temperature. If the host stops sending it for any reason (the daemon crashes, the
host hangs or reboots), the controller keeps driving the fans on its own:

- **Clean stop.** When the daemon receives SIGTERM (`systemctl stop`, host shutdown), it
  sends `BYE`. The controller then rests at 20 % instead of treating the silence as a
  failure.
- **Silence without `BYE`.** After 30 s without a temperature, the controller switches
  to failsafe and runs all fans at 100 %.
- **Daemon restart.** The service restarts the daemon automatically. On connecting it
  sends `HELLO`; when temperatures arrive again, the controller returns to the curve.

A host restart therefore never stops the cooling.

The daemon owns the serial port. The other `fanctl` commands talk to the daemon through
a Unix socket. When the daemon is not running, they open the serial port directly.

## Requirements

- **Proxmox VE** (Debian). `fanctl` itself runs on any Linux host; `install.sh` needs
  systemd and udev. Run the installer and the `fanctl` commands as root.
- **Python 3, standard library only.** No other packages are needed.
- **An Intel or AMD CPU.** The daemon reads the CPU temperature from the kernel's
  hwmon devices:

  | hwmon driver | CPUs | Sensor used |
  |---|---|---|
  | `coretemp` | Intel | `Package id N` |
  | `k10temp` | AMD (Ryzen, EPYC, Athlon, ...) | `Tdie` if present, otherwise `Tctl` |
  | `zenpower` | AMD, out-of-tree replacement for `k10temp` | `Tdie` if present, otherwise `Tctl` |

  If a device has none of these labels, the daemon uses its hottest reading. On hosts
  with more than one CPU package the hottest package wins. Devices are found by name
  every time, because hwmon numbers can change between boots. The daemon logs which
  sensors it reads, for example `CPU temperature from k10temp Tctl`.

> [!NOTE]
> On some older AMD CPUs (for example Ryzen 7 1700X/1800X, Threadripper 1000/2000)
> `Tctl` reads 10–27 °C above the real temperature. Where the kernel knows that
> offset it also provides `Tdie`, which the daemon prefers. Without a supported
> device the daemon sends no temperature, so the controller runs the fans at 100 %
> (failsafe).

To check which hwmon devices the host has:

```sh
cat /sys/class/hwmon/hwmon*/name
```

## Installation

1. Flash the controller as described in [firmware.md](firmware.md) and connect it to
   the host over USB.
2. Copy the [`host/`](../host/) directory to the host.
3. On the host, run the installer as root:

   ```sh
   sh install.sh
   ```

[`host/install.sh`](../host/install.sh) performs these steps:

| Step | Command |
|---|---|
| 1. Install the tool | `install -m 755 fanctl /usr/local/bin/fanctl` |
| 2. Install the udev rule | `install -m 644 99-fanctl.rules /etc/udev/rules.d/99-fanctl.rules` |
| 3. Install the systemd unit | `install -m 644 fanctl.service /etc/systemd/system/fanctl.service` |
| 4. Load the rule and apply it to existing serial devices | `udevadm control --reload` and `udevadm trigger --subsystem-match=tty` |
| 5. Load the unit, then enable and start the service | `systemctl daemon-reload` and `systemctl enable --now fanctl` |
| 6. Show the result | The first lines of `systemctl status fanctl`, then `ls -l /dev/fanctl` |

If the controller is not plugged in, the last step prints:

```text
No /dev/fanctl - the controller is not plugged in (the daemon is waiting).
```

This is not an error. The daemon connects as soon as the device appears.

When the installation is complete, check the controller:

```sh
fanctl status
```

## Installed files

| File | Source | Purpose |
|---|---|---|
| `/usr/local/bin/fanctl` | [`host/fanctl`](../host/fanctl) | The daemon and the command-line tool |
| `/etc/udev/rules.d/99-fanctl.rules` | [`host/99-fanctl.rules`](../host/99-fanctl.rules) | Stable device name `/dev/fanctl` |
| `/etc/systemd/system/fanctl.service` | [`host/fanctl.service`](../host/fanctl.service) | Runs `fanctl daemon` as a service |

While it runs, the daemon also creates the Unix socket `/run/fanctl.sock` (mode `0660`).
It removes the socket when it stops cleanly.

### udev rule

```text
SUBSYSTEM=="tty", ATTRS{idVendor}=="2e8a", ATTRS{idProduct}=="0005", SYMLINK+="fanctl", MODE="0660", ENV{ID_MM_DEVICE_IGNORE}="1"
```

- USB vendor `2e8a`, product `0005` is a Raspberry Pi Pico running MicroPython.
- The rule creates the symlink **`/dev/fanctl`**. The underlying `/dev/ttyACMx` name can
  change when the USB device is reconnected, but the symlink always points to the
  controller.
- `MODE="0660"` restricts access to the device's owner and group.
- `ENV{ID_MM_DEVICE_IGNORE}="1"` tells ModemManager to leave the port alone, so it does
  not probe the controller as a modem.

### systemd service

| Setting | Value | Effect |
|---|---|---|
| `ExecStart` | `/usr/local/bin/fanctl daemon` | Runs the daemon |
| `After` | `systemd-udevd.service` | Starts after udev |
| `KillSignal` | `SIGTERM` | On stop, the daemon sends `BYE` and the controller rests at 20 % instead of going to failsafe |
| `TimeoutStopSec` | `10` | Time allowed for a clean stop |
| `Restart` | `always` | Restarts the daemon whenever it exits |
| `RestartSec` | `5` | Waits 5 s before a restart |
| `WantedBy` | `multi-user.target` | Starts at boot |

The daemon logs to standard output, so its messages go to the systemd journal:

```sh
journalctl -u fanctl -f
```

## The fanctl command

```text
fanctl [--device PATH] [--socket PATH] [--reply-timeout S] {daemon,status,send,calibrate} ...
```

Global options go **before** the subcommand.

| Option | Default | Description |
|---|---|---|
| `--device` | `/dev/fanctl`, or the `FANCTL_DEVICE` environment variable | Serial device of the controller |
| `--socket` | `/run/fanctl.sock`, or the `FANCTL_SOCKET` environment variable | Unix socket of the daemon |
| `--reply-timeout` | `2.0` | Seconds to wait for a reply from the controller |

### fanctl daemon

Runs the service loop. You normally start it through systemd, not by hand.

| Option | Default | Description |
|---|---|---|
| `--interval` | `5` | Seconds between updates |
| `--hwmon` | `/sys/class/hwmon` | hwmon directory (used by the tests) |

Behaviour:

- **Startup.** The daemon logs `fanctl daemon: /dev/fanctl, every 5 s`.
- **Controller missing.** If the device cannot be opened, the daemon logs
  `no controller at /dev/fanctl (<reason>) - waiting` once and retries at every
  interval.
- **Controller found.** The daemon logs `connected to /dev/fanctl`, sends `VER` and logs
  the reply, for example `VER FanCtrl3 <version>`, then sends `HELLO`. `HELLO` takes the
  controller out of rest mode left by an earlier `BYE`, so a daemon that cannot read a
  temperature still ends in failsafe (100 %) instead of leaving the fans at 20 %.
- **Controller lost.** The daemon logs `lost the controller: <reason>` and returns to
  waiting.
- **No temperature.** If no CPU temperature is found, the daemon does not send
  `TEMP`. It logs this once, and logs again when a sensor appears
  (`CPU temperature from <driver> <label>`).
- **Controller messages.** `ALARM`, `INFO` and `ERR` lines from the controller are
  written to the log. The daemon also keeps the 20 most recent ones, with timestamps,
  for `fanctl status`.
- **Stopping.** On SIGTERM or SIGINT the daemon sends `BYE`, logs the reply
  (`BYE -> OK REST`), removes the socket and logs `fanctl daemon: stopped`.

### fanctl status

Shows the controller's state in readable form.

If the daemon is running, the command shows the status the daemon collected at its last
update (at most one interval old), followed by the five most recent controller
messages. If the daemon is running but the controller is not connected, it prints
`the daemon is running, but the controller is not connected`. If the daemon is not
running, the command asks the controller directly.

Example:

```text
mode:        curve
CPU:         54.0 °C (3 s ago)
ambient:     27.5 °C
USB overload: no
fan 1:        54%    728 rpm
fan 2:        54%    728 rpm (manual)
fan 3:        54%    728 rpm
recent messages:
  <HH:MM:SS> <message>
```

| Line | Source ([STAT fields](firmware.md#the-stat-line)) |
|---|---|
| `mode` | `curve` (`auto`), `start (waiting for the first temperature)`, `rest after BYE` or `FAILSAFE 100% (no temperature)` |
| `CPU` | Last temperature sent to the controller and its age. Shows `-` if none has been sent. |
| `ambient` | DS18B20 reading. Shows `-` if there is no probe or no valid reading. |
| `USB overload` | `YES` while the TPS2553 power switch reports a fault |
| `fan N` | Output duty and measured speed. `(manual)` marks a fan set with `SET`. |

### fanctl send

Sends one raw protocol command and prints the controller's reply. See
[firmware.md](firmware.md#serial-protocol) for the full command list.

```sh
fanctl send PING                         # PONG
fanctl send SET 1 40                     # OK   (fan 1 manual at 40 %)
fanctl send SET 1 AUTO                   # OK
fanctl send CURVE 35:20 50:35 65:60 75:100
fanctl send SAVE                         # OK SAVE
fanctl send CONF                         # CONF {"curve": [[35, 20], ...], ...}
```

If the controller does not reply within the reply timeout, the command prints `None`.
If the daemon is running but has no controller connected, it exits with
`error: no controller`.

### fanctl calibrate

```text
fanctl calibrate [N] [--settle S] [--margin M]
```

| Argument | Default | Description |
|---|---|---|
| `N` | all fans | Fan to calibrate: 1, 2 or 3 |
| `--settle` | `6` | Seconds to wait at each step before reading the speed |
| `--margin` | `5` | Percentage points added above the lowest working duty |

See the next section for details.

## Calibrating the minimum duty

A fan can stop turning when its PWM duty is too low. The controller never drives a fan
below its `min_duty` (default 20 %). `fanctl calibrate` measures the real minimum of each fan
and stores it on the controller.

Run it with the daemon active, so the controller keeps receiving temperatures during
the measurement:

```sh
fanctl calibrate        # all three fans
fanctl calibrate 2      # fan 2 only
```

For each fan, the tool:

1. reads the current configuration with `CONF`, to keep the old minimum,
2. sets the fan's minimum to 0 (`MIN n 0`) so the controller allows low duties,
3. steps the fan's duty down from 60 % to 0 % in 5 % steps (`SET n <duty>`):
   - waits until the controller's output reaches the requested duty (up to 30 s,
     because the controller ramps down at 2 % per second),
   - waits `--settle` seconds, then reads the fan speed,
   - stops at the first step where the fan reports 0 rpm,
4. returns the fan to automatic control (`SET n AUTO`),
5. sets the minimum to the lowest duty at which the fan still turned, plus the margin
   (at most 100 %).

When all fans are done, the tool sends `SAVE` so the new minimums survive a restart —
only if at least one new minimum was measured; otherwise it prints
`nothing measured - nothing saved`.

If the fan does not turn even at 60 %, or the measurement is interrupted, the tool
restores the fan's previous minimum.

Example output:

```text
fan 1: stepping the duty down 60% -> 0% in 5% steps, 6 s per step
   60% -> <rpm> rpm
   55% -> <rpm> rpm
   ...
   20% -> <rpm> rpm
   15% -> 0 rpm
  lowest working duty: 20% -> MIN 25% (margin 5)
save: OK SAVE
```

For a fan that does not turn:

```text
  fan 3 does not spin even at 60% - is it connected? MIN stays at 20%
```

> [!NOTE]
> The controller's safety rules still apply during calibration. `calibrate` refuses to
> start while the controller is in failsafe (no temperature — start the daemon first),
> and it stops, keeping the old minimum, when the controller does not follow the
> requested duty within 30 s (failsafe or a hot-ambient override).

> [!NOTE]
> `SAVE` stores the controller's complete configuration, including any other unsaved
> changes made with `CURVE`, `MIN` or `ENABLE`.

## Troubleshooting

### The daemon logs "no controller at /dev/fanctl … - waiting"

The daemon cannot open `/dev/fanctl`. It retries at every interval and connects
automatically when the device appears.

- Check that the controller is connected: `ls -l /dev/fanctl`.
- The udev rule matches only a Pico running MicroPython (USB `2e8a:0005`). A Pico in
  BOOTSEL mode, or one without MicroPython, does not get the `/dev/fanctl` link.
- If you installed the rule while the controller was already connected, run
  `udevadm trigger --subsystem-match=tty` or reconnect the controller.

### All fans run at 100 % and the mode is FAILSAFE

The controller has not received a temperature for more than 30 s.

- Check that the service is running: `systemctl status fanctl`.
- Check the log with `journalctl -u fanctl`. If it shows
  `no CPU temperature (coretemp, k10temp or zenpower)`, the host has no supported
  hwmon device (see [Requirements](#requirements)). Check that the driver is loaded,
  for example `modprobe k10temp`.
- As soon as temperatures arrive again, the controller returns to the curve.

A controller that has received `BYE` stays in rest mode (20 %) until the next
temperature, and does not switch to failsafe.

### The fans stay at 20 % after the service was stopped

This is expected. On `systemctl stop fanctl` the daemon sends `BYE`, and the controller
stays at rest duty until it receives a temperature again.

### A second Pico is connected to the same host

The udev rule matches every Pico running MicroPython. If the host has more than one,
tie the rule to the controller's USB serial number. Read the serial number:

```sh
udevadm info -a -n /dev/ttyACM0 | grep serial
```

Then add `ATTRS{serial}=="<serial>"` to `/etc/udev/rules.d/99-fanctl.rules`:

```text
SUBSYSTEM=="tty", ATTRS{idVendor}=="2e8a", ATTRS{idProduct}=="0005", ATTRS{serial}=="<serial>", SYMLINK+="fanctl", MODE="0660", ENV{ID_MM_DEVICE_IGNORE}="1"
```

Reload the rule with `udevadm control --reload` and
`udevadm trigger --subsystem-match=tty`.

### A header without a fan raises stall alarms

Disable stall detection for that header and save the change:

```sh
fanctl send ENABLE 3 0
fanctl send SAVE
```

### Updating the controller firmware

The daemon holds the serial port open. Stop it with `systemctl stop fanctl` before you
use `mpremote`, then follow [firmware.md](firmware.md#copying-the-firmware). Start the
daemon again with `systemctl start fanctl`.

## Uninstalling

`install.sh` puts these three files in place:

- `/usr/local/bin/fanctl`
- `/etc/udev/rules.d/99-fanctl.rules`
- `/etc/systemd/system/fanctl.service`

To remove them, run as root:

```sh
systemctl disable --now fanctl
rm /etc/systemd/system/fanctl.service
rm /etc/udev/rules.d/99-fanctl.rules
rm /usr/local/bin/fanctl
systemctl daemon-reload
udevadm control --reload
```

The daemon removes `/run/fanctl.sock` when it stops. The `/dev/fanctl` symlink disappears
the next time you disconnect the controller.

> [!WARNING]
> Stopping the service sends `BYE`, so the controller keeps the fans at rest duty (20 %)
> with no further temperature input. After a power cycle without a host daemon, the
> controller starts at 60 % and switches to failsafe (100 %) after 30 s.

The configuration saved on the controller (`/fanctrl3.json`) is not affected.

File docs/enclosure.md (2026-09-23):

# Enclosure

One parametric OpenSCAD file,
[`hardware/enclosure/FanCtrl3-enclosure.scad`](../hardware/enclosure/FanCtrl3-enclosure.scad),
produces a base and a lid for each variant. Ready-to-print STL files are in
[`hardware/enclosure/stl/`](../hardware/enclosure/stl/).

| File | Size (X × Y × Z) |
|---|---|
| `FanCtrl3-lite-base.stl` | 77.6 × 66.6 × 27.6 mm |
| `FanCtrl3-lite-lid.stl` | 77.6 × 66.6 × 3.5 mm |
| `FanCtrl3-pro-base.stl` | 95.6 × 79.6 × 22.6 mm |
| `FanCtrl3-pro-lid.stl` | 95.6 × 79.6 × 3.5 mm |

| Lite | Pro |
|---|---|
| Lite enclosure preview | Pro enclosure preview |

## Design

- **Free-standing** next to the server: no mounting ears, four shallow pockets
  (Ø 9 × 1 mm) in the floor for 8 × 2 mm self-adhesive rubber feet.
- The board sits on **four 5 mm standoffs** — room for solder joints and the
  perfboard wiring underneath — and is held by **M3 × 8 screws** driven from above
  into Ø 2.6 mm pilot holes (the screw cuts its own thread in PETG).
- The lid is held by **four M3 × 8 screws** in corner bosses that sit outside the
  board outline, so they never collide with components. A 1.5 mm lip centres it.
- Openings: the Pico's micro-USB in the left wall (12 × 8 mm, room for the plug's
  overmould); three 12 × 9 mm openings in the lid above the fan headers (the fan
  plugs go in from the top); a Ø 6 mm entry for the probe cable (front wall on
  Pro, right wall on Lite); a Ø 5 mm window above the Pico's LED; vent slots above
  the 12 V converter.
- Engraved labels on the lid: "FanCtrl3 Pro" / "FanCtrl3 Lite" and the fan
  numbers 1–3.
- 2 mm walls, floor and lid.

8 × M3 × 8 screws per enclosure (4 for the board, 4 for the lid).

## Printing

- **PETG**, no supports, any infill.
- The base prints **bottom down**. The lid STL is already flipped: print it **top
  down** as it comes.
- The probe entry is teardrop-shaped and the top of the USB opening is a 12 mm
  bridge, so neither needs supports.

> [!IMPORTANT]
> **Lite only:** the position of the PC-3 perfboard's mounting holes (3.0 mm from
> the edge, Ø 3.5 mm) was taken from the distributor's product photo, not from a
> drawing. Measure your board with calipers before printing the base; if it
> differs, change `hole_inset` / `hole_d` in the `.scad` file and rebuild.

## Checked

- **Collision test:** the file has a `part="collisions"` mode that intersects the
  enclosure with simplified bodies of every component (heights included). The
  result must be empty, and it is for both variants. The test was checked with a
  deliberately oversized component, which it does report.
- The USB opening lines up with the Pico's socket in both variants.

Assumed, not yet measured on real parts: the height of the electrolytic
capacitors (11–12 mm), the fan headers with a plug inserted (12 mm), the Pico
standing in its sockets on Lite (11 mm above the board), and the position of the
Pico's LED.

## Rebuilding

```bash
hardware/tools/build_enclosure.sh
```

Needs [OpenSCAD](https://openscad.org/) 2024 or newer (Manifold backend). The
Lite component positions come from
[`FanCtrl3-lite-geometry.scad`](../hardware/enclosure/FanCtrl3-lite-geometry.scad),
which `build_lite.sh` generates from the perfboard design — run that first if you
change the Lite layout. See [development.md](development.md).

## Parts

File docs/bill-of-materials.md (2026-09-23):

# Bill of materials

Everything needed to build one controller, for each variant. Part numbers are
**TME order codes** because TME stocks nearly the whole list in one place and ships
across Europe.

> [!NOTE]
> The shop links are **only a suggestion** of where most of the parts can be bought
> in one order. They are not affiliate links, and nothing here depends on a
> particular shop — any part with the same value, rating and footprint will do.
> Availability and prices change; check the page before you order.

"Qty" is what one controller uses. "Buy" is a sensible order quantity where the
shop sells in packs or where a spare is worth having (small SMD chips are easy to
overheat by hand).

## FanCtrl3 Lite — modules on a perfboard

Through-hole parts and ready-made modules, no custom PCB. Wiring:
[`hardware/lite/FanCtrl3-Lite-wiring.md`](../hardware/lite/FanCtrl3-Lite-wiring.md).

| # | Part | Used for | Ref | Qty | Buy | Order code / link |
|---|---|---|---|---|---|---|
| 1 | Raspberry Pi Pico | microcontroller | U1 | 1 | 1 | [SC0915](https://www.tme.eu/en/details/sc0915/raspberry-pi-embedded/raspberry-pi/raspberry-pi-pico/) |
| 2 | Pololu U3V16F12, fixed 12 V step-up | 5 V → 12 V for the fans | U2 | 1 | 1 | [POLOLU-4945](https://www.tme.eu/en/details/pololu-4945/converter-modules/pololu/12v-step-up-voltage-regulator-u3v16f12/) · [Pololu](https://www.pololu.com/product/4945) |
| 3 | TPS2553DBVR current-limited switch, SOT-23-6 | protects the host USB port, reports overload | U3 | 1 | 2 | [TPS2553DBVR](https://www.tme.eu/en/details/tps2553dbvr/power-switches-integrated-circuits/texas-instruments/) |
| 4 | SparkFun SOT-23 to DIP-6 adapter, BOB-00717 | carries the TPS2553 on the perfboard | U3 | 1 | 1 | [SparkFun](https://www.sparkfun.com/sparkfun-sot23-to-dip-adapter.html) · [Botland](https://botland.store/adapters-smd-dip/1760-adapter-sot23-to-dip-6-pin-sparkfun-bob-00717-5904422369965.html) — not stocked by TME |
| 5 | BC547B NPN transistor, TO-92 | open-collector PWM output | Q1–Q3 | 3 | 5 | [BC547B-DIO](https://www.tme.eu/en/details/bc547b-dio/npn-tht-transistors/diotec-semiconductor/bc547b/) |
| 6 | Resistor 4.7 kΩ, 0.25 W, axial | base resistors, tach and 1-Wire pull-ups | R1, R4, R5, R8, R9, R12, R13 | 7 | 100 | [CF1/4W-4K7](https://www.tme.eu/en/details/cf1_4w-4k7/tht-resistors/sr-passives/) |
| 7 | Resistor 10 kΩ, 0.25 W, axial | base pull-downs, tach series, limiter pull-ups | R2, R3, R6, R7, R10, R11, R15, R16 | 8 | 100 | [CF1/4W-10K](https://www.tme.eu/en/details/cf1_4w-10k/tht-resistors/sr-passives/) |
| 8 | Resistor 51 kΩ, 0.25 W, axial | current limit setting (465–570 mA) | R14 | 1 | 100 | [CF1/4W-51K](https://www.tme.eu/en/details/cf1_4w-51k/tht-resistors/sr-passives/) |
| 9 | Ceramic capacitor 100 nF 50 V X7R, 2.54 mm leads (AVX SR20) | limiter input | C3 | 1 | 1 | [SR205C104KAR](https://www.tme.eu/en/details/sr205c104kar/mlcc-tht-capacitors/kyocera-avx/) |
| 10 | Electrolytic 47 µF 25 V, Ø5 × 11 mm | converter input (Pololu recommends ≥ 33 µF) | C1 | 1 | 20 | [CE-47/25PHT-Y](https://www.tme.eu/en/details/ce-47_25pht-y/tht-electrolytic-capacitors/aishi/ewh1ev470d11ot/) |
| 11 | Electrolytic 100 µF 25 V, Ø6.3 × 11 mm | 12 V rail | C2 | 1 | 20 | [CE-100/25PHT-Y](https://www.tme.eu/en/details/ce-100_25pht-y/tht-electrolytic-capacitors/aishi/ewh1ev101e11ot/) |
| 12 | Molex KK 254 4-pin header 47053-1000 | fan connectors (standard 4-pin PWM) | J1–J3 | 3 | 3 | [MX-47053-1000](https://www.tme.eu/en/details/mx-47053-1000/raster-signal-connectors-2-54mm/molex/47053-1000/) |
| 13 | 3-pole screw terminal, 2.54 mm | DS18B20 probe | J4 | 1 | 2 | [DG308-2.54-03P](https://www.tme.eu/en/details/dg308-2.54-03p/pcb-terminal-blocks/degson-electronics/dg308-2-54-03p-14-00ah/) |
| 14 | DS18B20 waterproof probe on a cable (DFRobot DFR0198) | ambient temperature | — | 1 | 1 | [DF-DFR0198](https://www.tme.eu/en/details/df-dfr0198/environmental-sensors/dfrobot/dfr0198/) |
| 15 | Perfboard SCI PC-3, 72 × 47 mm, single-sided | the board | — | 1 | 2 | [PC-3](https://www.tme.eu/en/details/pc-3/universal-pcbs/sci/) |
| 16 | Pin header 1 × 20, 2.54 mm | soldered to the Pico; 6 pins for the adapter | — | 2 + 6 pins | 10 | [ZL201-20G](https://www.tme.eu/en/details/zl201-20g/pin-headers/connfly/ds1021-1-20sf11-b/) |
| 17 | Socket 1 × 20, 2.54 mm | makes the Pico removable | — | 2 | 2 | [ZL262-20SG](https://www.tme.eu/en/details/zl262-20sg/pin-headers/connfly/ds1023-1-20s21/) |
| 18 | Jumper wire kit, 140 pcs (MIKROE-2022) | insulated and bare wiring on the board | — | 1 | 1 | [MIKROE-2022](https://www.tme.eu/en/details/mikroe-2022/development-kits-accessories/mikroe/) |
| 19 | USB-A to micro-USB cable, 1 m | to the host | — | 1 | 1 | [QOLTEC-50214](https://www.tme.eu/en/details/qoltec-50214/usb-cables-and-adapters/qoltec/50214/) |
| 20 | Self-adhesive rubber foot, 8 × 2 mm | enclosure | — | 4 | 10 | [RF8-2A](https://www.tme.eu/en/details/rf8-2a/feet/fix-fasten/) |
| 21 | Socket-head screw M3 × 8 (DIN 912) | board and lid | — | 8 | 100 | [B3X8/BN612](https://www.tme.eu/en/details/b3x8_bn612/bolts/bossard/1233793/) |

Plus the printed enclosure — see [enclosure.md](enclosure.md).

> [!TIP]
> Use a USB cable that carries data, not a charge-only one. Items 19–21 are
> generic: any data-capable micro-USB cable, any small rubber feet and any M3 × 8
> screws will do.

## FanCtrl3 Pro — custom PCB, hand-soldered

Two-layer PCB (90 × 60 mm), all parts chosen for a soldering iron: 0805/1206
passives, SOT-23 packages, no QFN or exposed pads. The Pico is soldered flat by its
castellated edge. The list below matches the KiCad BOM,
[`hardware/pro/fabrication/FanCtrl3-Pro-BOM.csv`](../hardware/pro/fabrication/FanCtrl3-Pro-BOM.csv).

| # | Part | Used for | Ref | Qty | Buy | Order code / link |
|---|---|---|---|---|---|---|
| 1 | Raspberry Pi Pico | microcontroller | U1 | 1 | 1 | [SC0915](https://www.tme.eu/en/details/sc0915/raspberry-pi-embedded/raspberry-pi/raspberry-pi-pico/) |
| 2 | TPS2553DBVR current-limited switch, SOT-23-6 | protects the host USB port, reports overload | U2 | 1 | 2 | [TPS2553DBVR](https://www.tme.eu/en/details/tps2553dbvr/power-switches-integrated-circuits/texas-instruments/) |
| 3 | LM27313XMF boost converter, SOT-23-5 | 5 V → 12.4 V for the fans | U3 | 1 | 2 | [LM27313XMF/NOPB](https://www.tme.eu/en/details/lm27313xmf_nopb/voltage-regulators-dc-dc-circuits/texas-instruments/) |
| 4 | Inductor 10 µH, 5 × 5 mm | boost converter | L1 | 1 | 5 | [DJNR5040-100-S](https://www.tme.eu/en/details/djnr5040-100-s/inductors/ferrocore/) |
| 5 | Schottky diode SS14, 40 V 1 A, SMA | boost converter | D1 | 1 | 2 | [SS14-FAI](https://www.tme.eu/en/details/ss14-fai/smd-schottky-diodes/onsemi/ss14/) |
| 6 | N-MOSFET 2N7002, SOT-23 | open-drain PWM output | Q1–Q3 | 3 | 5 | [2N7002-DIO](https://www.tme.eu/en/details/2n7002-dio/smd-n-channel-transistors/diotec-semiconductor/2n7002/) |
| 7 | Ceramic 10 µF 25 V X7R, 1206 | converter input and output | C2, C4, C5 | 3 | 5 | [TMK316AB7106KLHT](https://www.tme.eu/en/details/tmk316ab7106klht/mlcc-smd-capacitors/taiyo-yuden/) |
| 8 | Ceramic 100 nF 50 V X7R, 0805 | decoupling | C1, C7 | 2 | 5 | [0805B104K500CT](https://www.tme.eu/en/details/0805b104k500ct/mlcc-smd-capacitors/walsin/) |
| 9 | Ceramic 220 pF 50 V C0G, 0805 | converter feed-forward | C3 | 1 | 2 | [0805N221J500CT](https://www.tme.eu/en/details/0805n221j500ct/mlcc-smd-capacitors/walsin/) |
| 10 | Electrolytic 100 µF 25 V, Ø6.3 × 11 mm | 12 V rail | C6 | 1 | 20 | [CE-100/25PHT-Y](https://www.tme.eu/en/details/ce-100_25pht-y/tht-electrolytic-capacitors/aishi/ewh1ev101e11ot/) |
| 11 | Resistor 10 kΩ 1 %, 0805 | divider (bottom), tach series, FAULT pull-up | R2, R6, R13–R15 | 5 | 100 | [SMD0805-10K-1%](https://www.tme.eu/en/details/smd0805-10k-1%25/smd-resistors/royalohm/0805s8f1002t5e/) |
| 12 | Resistor 4.7 kΩ 1 %, 0805 | tach and 1-Wire pull-ups | R10–R12, R16 | 4 | 100 | [SMD0805-4K7-1%](https://www.tme.eu/en/details/smd0805-4k7-1%25/smd-resistors/royalohm/0805s8f4701t5e/) |
| 13 | Resistor 100 kΩ 1 %, 0805 | gate pull-downs, EN pull-up | R3, R7–R9 | 4 | 100 | [SMD0805-100K-1%](https://www.tme.eu/en/details/smd0805-100k-1%25/smd-resistors/royalohm/0805s8f1003t5e/) |
| 14 | Resistor 91 kΩ 1 %, 0805 | divider (top) → 12.4 V | R5 | 1 | 100 | [SMD0805-91K-1%](https://www.tme.eu/en/details/smd0805-91k-1%25/smd-resistors/royalohm/0805s8f9102t5e/) |
| 15 | Resistor 51 kΩ 1 %, 0805 | current limit, converter shutdown pull-up | R1, R4 | 2 | 100 | [SMD0805-51K-1%](https://www.tme.eu/en/details/smd0805-51k-1%25/smd-resistors/royalohm/0805s8f5102t5e/) |
| 16 | Molex KK 254 4-pin header 47053-1000 | fan connectors | J1–J3 | 3 | 3 | [MX-47053-1000](https://www.tme.eu/en/details/mx-47053-1000/raster-signal-connectors-2-54mm/molex/47053-1000/) |
| 17 | 3-pole screw terminal, 2.54 mm | DS18B20 probe | J4 | 1 | 2 | [DG308-2.54-03P](https://www.tme.eu/en/details/dg308-2.54-03p/pcb-terminal-blocks/degson-electronics/dg308-2-54-03p-14-00ah/) |
| 18 | DS18B20 waterproof probe on a cable | ambient temperature | — | 1 | 1 | [DF-DFR0198](https://www.tme.eu/en/details/df-dfr0198/environmental-sensors/dfrobot/dfr0198/) |
| 19 | USB-A to micro-USB cable, 1 m | to the host | — | 1 | 1 | [QOLTEC-50214](https://www.tme.eu/en/details/qoltec-50214/usb-cables-and-adapters/qoltec/50214/) |
| 20 | Self-adhesive rubber foot, 8 × 2 mm | enclosure | — | 4 | 10 | [RF8-2A](https://www.tme.eu/en/details/rf8-2a/feet/fix-fasten/) |
| 21 | Socket-head screw M3 × 8 (DIN 912) | board and lid | — | 8 | 100 | [B3X8/BN612](https://www.tme.eu/en/details/b3x8_bn612/bolts/bossard/1233793/) |
| 22 | Bare PCB, 2 layers, 1.6 mm, 90 × 60 mm | the board | — | 1 | 5 | any PCB fab — see [build-pro.md](build-pro.md) |

Plus the printed enclosure — see [enclosure.md](enclosure.md).

## Datasheets

| Part | Datasheet |
|---|---|
| Raspberry Pi Pico | [pico-datasheet.pdf](https://datasheets.raspberrypi.com/pico/pico-datasheet.pdf) |
| TI TPS2553 | [ti.com/lit/gpn/TPS2553](https://www.ti.com/lit/gpn/TPS2553) |
| TI LM27313 | [ti.com/lit/ds/symlink/lm27313.pdf](https://www.ti.com/lit/ds/symlink/lm27313.pdf) |
| Pololu U3V16F12 | [pololu.com/product/4945](https://www.pololu.com/product/4945) |
| SparkFun BOB-00717 | [schematic (PDF)](https://cdn.sparkfun.com/datasheets/BreakoutBoards/SparkFun_SOT23-DIP-Adapter-v10.pdf) · [design files](https://github.com/sparkfun/SOT23_DIP_Adapter) |
| KYOCERA AVX SkyCap SR | [SR-Series.pdf](https://datasheets.kyocera-avx.com/SR-Series.pdf) |

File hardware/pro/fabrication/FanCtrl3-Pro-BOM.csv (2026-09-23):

References | Value | Footprint | TME | Qty | Note
C1,C7 | 100n | Capacitor_SMD:C_0805_2012Metric_Pad1.18x1.45mm_HandSolder | 0805B104K500CT | 2
C2,C4,C5 | 10u 25V | Capacitor_SMD:C_1206_3216Metric_Pad1.33x1.80mm_HandSolder | TMK316AB7106KLHT | 3
C3 | 220p | Capacitor_SMD:C_0805_2012Metric_Pad1.18x1.45mm_HandSolder | 0805N221J500CT | 1 | feed-forward, fz ~ 8 kHz
C6 | 100u 25V | Capacitor_THT:CP_Radial_D6.3mm_P2.50mm | CE-100/25PHT-Y | 1
D1 | SS14 | Diode_SMD:D_SMA_Handsoldering | SS14-FAI | 1
J1,J2,J3 | FAN1,FAN2,FAN3 | Connector_Molex:Molex_KK-254_AE-6410-04A_1x04_P2.54mm_Vertical | MX-47053-1000 | 3
J4 | DS18B20 | TerminalBlock:TerminalBlock_Xinya_XY308-2.54-3P_1x03_P2.54mm_Horizontal | DG308-2.54-03P | 1 | probe: red VDD, yellow DQ, black GND
L1 | 10u | Inductor_SMD:L_Changjiang_FNR5040S | DJNR5040-100-S | 1
Q1,Q2,Q3 | 2N7002 | Package_TO_SOT_SMD:SOT-23_Handsoldering | 2N7002-DIO | 3
R1,R4 | 51k | Resistor_SMD:R_0805_2012Metric_Pad1.20x1.40mm_HandSolder | SMD0805-51K-1% | 2 | current limit 465-570 mA
R2,R6,R13,R14,R15 | 10k | Resistor_SMD:R_0805_2012Metric_Pad1.20x1.40mm_HandSolder | SMD0805-10K-1% | 5 | limits current if fan tach is pulled up to 12 V
R3,R7,R8,R9 | 100k | Resistor_SMD:R_0805_2012Metric_Pad1.20x1.40mm_HandSolder | SMD0805-100K-1% | 4 | MCU dead -> MOSFET off -> fan 100%,fans powered by default
R5 | 91k | Resistor_SMD:R_0805_2012Metric_Pad1.20x1.40mm_HandSolder | SMD0805-91K-1% | 1 | Vout = 1.23 * (1 + 91/10) = 12.4 V
R10,R11,R12,R16 | 4k7 | Resistor_SMD:R_0805_2012Metric_Pad1.20x1.40mm_HandSolder | SMD0805-4K7-1% | 4 | pull-up on fan side
U1 | Raspberry Pi Pico | Module:RaspberryPi_Pico_SMD_HandSolder | SC0915 | 1
U2 | TPS2553DBV | Package_TO_SOT_SMD:SOT-23-6_Handsoldering | TPS2553DBVR | 1
U3 | LM27313XMF | Package_TO_SOT_SMD:SOT-23-5_HandSoldering | LM27313XMF/NOPB | 1

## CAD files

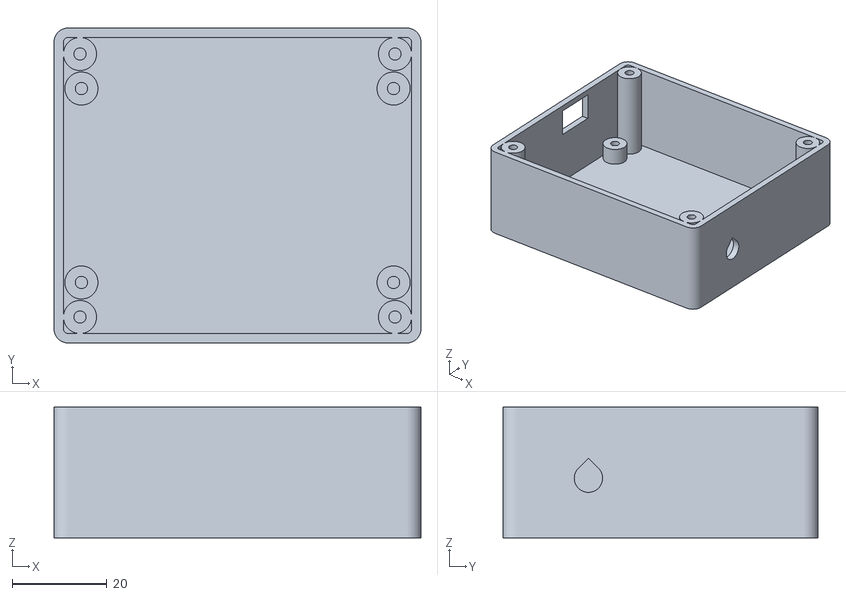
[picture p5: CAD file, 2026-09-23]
hardware/enclosure/stl/FanCtrl3-lite-base.stl
77.6 x 66.6 x 27.6

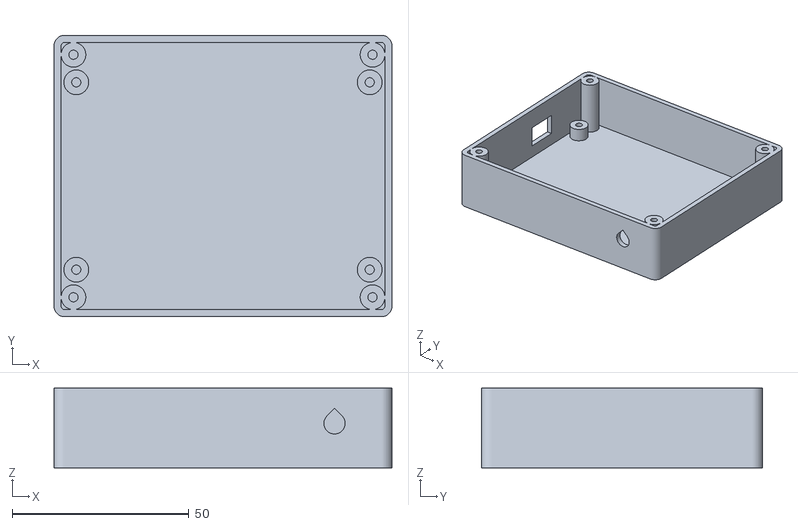
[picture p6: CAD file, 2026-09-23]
hardware/enclosure/stl/FanCtrl3-pro-base.stl
95.6 x 79.6 x 22.6

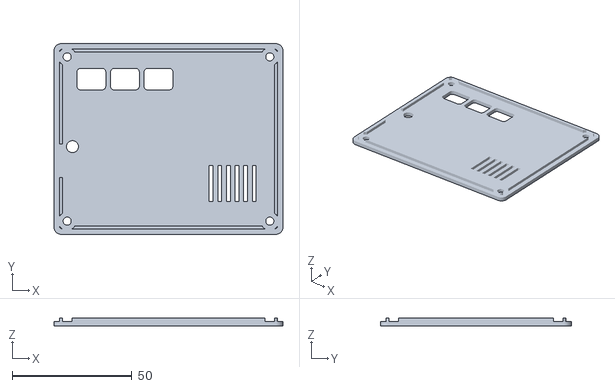
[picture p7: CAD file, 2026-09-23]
hardware/enclosure/stl/FanCtrl3-pro-lid.stl
95.6 x 79.6 x 3.50

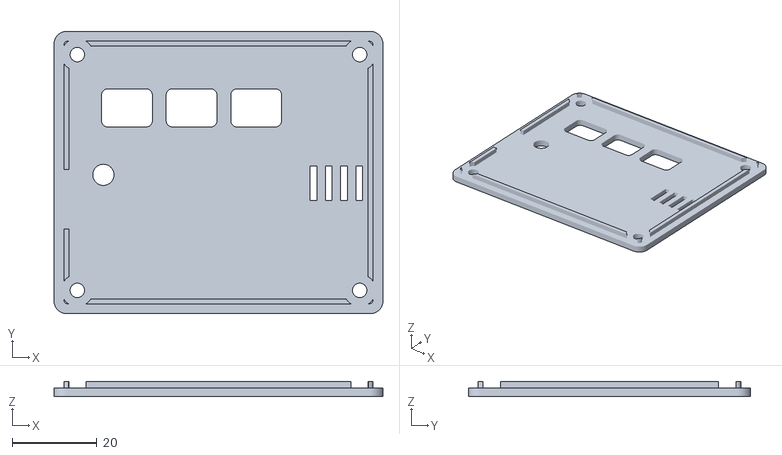
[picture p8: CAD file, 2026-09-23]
hardware/enclosure/stl/FanCtrl3-lite-lid.stl
77.6 x 66.6 x 3.50

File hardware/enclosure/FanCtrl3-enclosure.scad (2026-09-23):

// FanCtrl3 enclosure - one parametric file for both variants.
//
//   openscad -D 'variant="pro"'  -D 'part="base"' -o pro-base.stl  FanCtrl3-enclosure.scad
//   openscad -D 'variant="lite"' -D 'part="lid"'  -o lite-lid.stl  FanCtrl3-enclosure.scad
//
// variant: "pro" (custom PCB 90 x 60 mm) or "lite" (PC-3 perfboard 72 x 47 mm)
// part:    "base", "lid", "assembly" (preview with the board), "collisions" (the
//          intersection of the enclosure and the component bodies - must be empty)
//
// Printing: PETG, no supports. The base prints bottom down, the lid top down (the
// lid STL is already flipped). 2 mm walls.
// Board: 4 x M3x8 screwed from above into the standoffs. Lid: 4 x M3x8 into bosses
// in the corners, outside the board outline. RF8-2A rubber feet sit in shallow
// pockets in the floor.
//
// Board coordinates as in KiCad / design_lite.py: x to the right, y down from the
// top edge, in mm. b() converts them to OpenSCAD coordinates (y up).

variant = "pro";
part = "assembly";

// Lite component positions - generated by tools/gen_lite.py from design_lite.py
include <FanCtrl3-lite-geometry.scad>

$fn = 48;

// --- common --------------------------------------------------------------------
wall = 2.0;           // side walls
floor_t = 2.0;        // floor
lid_t = 2.0;          // lid plate
gap = 0.8;            // clearance between board edge and wall
strip = 7.0;          // extra room above and below the board for the lid bosses
outer_r = 3.0;        // outer corner radius
pcb_t = 1.6;
standoff_h = 5.0;     // standoff height (room for solder joints and wires below)
standoff_d = 7.0;
pilot_d = 2.6;        // pilot hole for an M3 screw cutting into PETG
pilot_depth = 6.5;    // M3x8: 1.6 mm board + 6.4 mm into the standoff
boss_d = 7.0;         // lid screw bosses
lid_hole_d = 3.4;
lip_h = 1.5;          // lid lip that drops into the base
lip_t = 1.2;
lip_gap = 0.3;
foot_d = 9.0;         // RF8-2A: 8 mm, 2 mm thick -> sticks out 1 mm
foot_depth = 1.0;
usb_w = 12;           // opening for the micro-USB plug including its overmould
usb_h = 8;
probe_d = 6;          // DS18B20 probe cable entry
fan_slot = [12, 9];   // lid opening above each fan header (plug is ~11 mm wide)
led_d = 5;
vent_w = 1.6;
vent_pitch = 3.6;
text_depth = 0.6;

// --- variants -------------------------------------------------------------------
pro = variant == "pro";
W = pro ? 90 : 72;
H = pro ? 60 : 47;
board_r = pro ? 3 : 0.5;
// lite: PC-3 mounting holes read off the distributor's product photo (3.0 mm from
// the edge, 3.5 mm diameter) - measure your board with calipers before printing
hole_inset = pro ? 3.5 : 3.0;
hole_d = pro ? 3.2 : 3.5;
top_clear = pro ? 14 : 19;              // board top to lid underside
// pro: from the KiCad board (FanCtrl3-Pro.kicad_pcb), lite: from the geometry file
usb_y = pro ? 21 : lite_usb_y;          // centre of the Pico micro-USB socket
usb_z = pro ? 2.3 : lite_usb_z;         // ... above the board top
fan_x = pro ? [12.81, 26.81, 40.81] : lite_fan_x;
fan_y = pro ? 55 : lite_fan_y;
probe_front = pro;                      // pro: probe enters at the front, lite: on the right
probe_pos = pro ? 76.54 : lite_probe_y; // x (front wall) or y (right wall)
probe_z = 4;                            // wire entry of the terminal above the board
led = pro ? [4.9, 26.8] : lite_led;
vent = pro ? [62, 4, 84, 19] : lite_vent;   // x0 y0 x1 y1

// --- derived dimensions ---------------------------------------------------------------
ix0 = -gap; ix1 = W + gap;
iy0 = -gap - strip; iy1 = H + gap + strip;
ox0 = ix0 - wall; ox1 = ix1 + wall;
oy0 = iy0 - wall; oy1 = iy1 + wall;
board_z = floor_t + standoff_h;          // board underside
top_z = board_z + pcb_t + top_clear;     // top of the walls = lid underside
holes = [[hole_inset, hole_inset], [W - hole_inset, hole_inset],
         [hole_inset, H - hole_inset], [W - hole_inset, H - hole_inset]];
bosses = [[ix0 + boss_d / 2, iy0 + boss_d / 2], [ix1 - boss_d / 2, iy0 + boss_d / 2],
          [ix0 + boss_d / 2, iy1 - boss_d / 2], [ix1 - boss_d / 2, iy1 - boss_d / 2]];

function b(x, y) = [x, H - y];

module rrect(x0, y0, x1, y1, r) {
    translate([x0, y0]) offset(r) offset(-r) square([x1 - x0, y1 - y0]);
}

module teardrop(d, len) {  // horizontal hole printable without supports, axis along Y
    rotate([90, 0, 0]) linear_extrude(len, center = true)
        union() { circle(d = d); rotate(45) square(d / 2); }
}

// --- base ---------------------------------------------------------------------
module base() {
    difference() {
        union() {
            difference() {
                linear_extrude(top_z) rrect(ox0, oy0, ox1, oy1, outer_r);
                translate([0, 0, floor_t])
                    linear_extrude(top_z) rrect(ix0, iy0, ix1, iy1, outer_r - wall);
            }
            for (p = bosses) translate(p) cylinder(d = boss_d, h = top_z);
            for (p = holes) translate(b(p[0], p[1])) cylinder(d = standoff_d, h = board_z);
        }
        for (p = bosses) translate([p[0], p[1], top_z - pilot_depth - 1])
            cylinder(d = pilot_d, h = pilot_depth + 2);
        for (p = holes) translate([each b(p[0], p[1]), board_z - pilot_depth])
            cylinder(d = pilot_d, h = pilot_depth + 1);
        // micro-USB in the left wall
        translate([ox0 - 1, H - usb_y - usb_w / 2, board_z + pcb_t + usb_z - usb_h / 2])
            cube([wall + gap + 2, usb_w, usb_h]);
        // probe cable entry
        if (probe_front)
            translate([probe_pos, oy0 + wall / 2, board_z + pcb_t + probe_z])
                teardrop(probe_d, wall + 2);
        else
            translate([ox1 - wall / 2, H - probe_pos, board_z + pcb_t + probe_z])
                rotate([0, 0, 90]) teardrop(probe_d, wall + 2);
        // foot pockets - under the lid bosses, away from the board screw holes
        for (p = bosses) translate([p[0], p[1], -1]) cylinder(d = foot_d, h = foot_depth + 1);
    }
}

// --- lid (in assembled position: plate from top_z up, lip down) ----------------
module lid() {
    difference() {
        union() {
            translate([0, 0, top_z]) linear_extrude(lid_t) rrect(ox0, oy0, ox1, oy1, outer_r);
            difference() {
                translate([0, 0, top_z - lip_h]) linear_extrude(lip_h + 0.01) difference() {
                    rrect(ix0 + lip_gap, iy0 + lip_gap, ix1 - lip_gap, iy1 - lip_gap, 1);
                    rrect(ix0 + lip_gap + lip_t, iy0 + lip_gap + lip_t,
                          ix1 - lip_gap - lip_t, iy1 - lip_gap - lip_t, 0.5);
                }
                for (p = bosses) translate([p[0], p[1], top_z - lip_h - 1])
                    cylinder(d = boss_d + 2 * lip_gap, h = lip_h + 2);
                // no lip above the USB plug
                translate([ix0 - 1, H - usb_y - usb_w / 2 - 1, top_z - lip_h - 1])
                    cube([lip_t + lip_gap + 2, usb_w + 2, lip_h + 2]);
            }
        }
        for (p = bosses) translate([p[0], p[1], top_z - 5]) cylinder(d = lid_hole_d, h = 10);
        for (x = fan_x) translate([each b(x, fan_y), top_z - 1])
            linear_extrude(lid_t + 2) rrect(-fan_slot[0] / 2, -fan_slot[1] / 2,
                                            fan_slot[0] / 2, fan_slot[1] / 2, 1.5);
        translate([each b(led[0], led[1]), top_z - 1]) cylinder(d = led_d, h = lid_t + 2);
        // vent slots above the boost converter
        for (x = [vent[0] : vent_pitch : vent[2] - vent_w])
            translate([x, H - vent[3], top_z - 1]) cube([vent_w, vent[3] - vent[1], lid_t + 2]);
        // engraved labels
        translate([0, 0, top_z + lid_t - text_depth]) linear_extrude(text_depth + 1) {
            translate(b(W / 2, fan_y - fan_slot[1] / 2 - 4))
                text(pro ? "FanCtrl3 Pro" : "FanCtrl3 Lite", size = 4, halign = "center",
                     valign = "center", font = "Liberation Sans:style=Bold");
            for (i = [0 : 2]) translate(b(fan_x[i], fan_y + fan_slot[1] / 2 + 3.5))
                text(str(i + 1), size = 3.5, halign = "center", valign = "center",
                     font = "Liberation Sans:style=Bold");
        }
    }
}

// --- component bodies (for the preview and the collision check) ---------------------------
module blk(x0, y0, x1, y1, z0, z1) {  // box in board coordinates
    translate([x0, H - y1, board_z + pcb_t + z0]) cube([x1 - x0, y1 - y0, z1 - z0]);
}
module cyl(x, y, d, z1) { translate([each b(x, y), board_z + pcb_t]) cylinder(d = d, h = z1); }
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

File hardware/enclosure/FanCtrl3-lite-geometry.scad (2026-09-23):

// Generated by tools/gen_lite.py from design_lite.py - do not edit by hand.
// PC-3 board coordinates in mm: x to the right, y down from the top edge.
lite_fan_x = [14.41, 29.65, 44.89];
lite_fan_y = 38.74;
lite_probe_y = 38.74;
lite_usb_y = 17.15;
lite_led = [8.85, 22.95];
lite_vent = [57.59, 16.9, 70.7, 25.02];
lite_usb_z = 13.3;
lite_boxes = [
    [57.59, 16.9, 70.7, 25.02, 0, 7],
    [57.64, 10.85, 62.62, 15.83, 0, 12],
    [59.52, 27.97, 65.82, 34.27, 0, 12],
    [60.64, 34.68, 67.24, 42.8, 0, 8.5],
    [57.67, 37.55, 60.05, 39.93, 0, 11],
    [9.33, 36.66, 19.49, 42.68, 0, 12],
    [4.38, 32.39, 11.74, 36.07, 0, 8],
    [6.87, 29.93, 9.25, 32.31, 0, 11],
    [6.87, 37.55, 9.25, 39.93, 0, 11],
    [11.95, 29.93, 14.33, 32.31, 0, 11],
    [14.49, 32.47, 16.87, 34.85, 0, 11],
    [24.57, 36.66, 34.73, 42.68, 0, 12],
    [19.62, 32.39, 26.98, 36.07, 0, 8],
    [22.11, 29.93, 24.49, 32.31, 0, 11],
    [22.11, 37.55, 24.49, 39.93, 0, 11],
    [27.19, 29.93, 29.57, 32.31, 0, 11],
    [29.73, 32.47, 32.11, 34.85, 0, 11],
    [39.81, 36.66, 49.97, 42.68, 0, 12],
    [34.86, 32.39, 42.22, 36.07, 0, 8],
    [37.35, 29.93, 39.73, 32.31, 0, 11],
    [37.35, 37.55, 39.73, 39.93, 0, 11],
    [42.43, 29.93, 44.81, 32.31, 0, 11],
    [44.97, 32.47, 47.35, 34.85, 0, 11],
    [21.27, 14.1, 32.95, 22.74, 0, 6],
    [14.41, 14.28, 19.49, 17.48, 0, 6.5],
    [35.39, 17.18, 41.69, 19.66, 0, 3],
    [35.39, 19.72, 41.69, 22.2, 0, 3],
    [12.53, 19.72, 18.83, 22.2, 0, 3],
    [4.15, 6.66, 55.15, 27.64, 11.0, 12.0],
    [4.25, 6.99, 55.05, 9.53, 0, 11.0],
    [4.25, 24.77, 55.05, 27.31, 0, 11.0],
    [3.15, 13.15, 9.15, 21.15, 12.0, 14.6]
];

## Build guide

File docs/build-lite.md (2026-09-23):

# Building FanCtrl3 Lite

The Lite variant is built from ready-made modules on a 72 × 47 mm perfboard (SCI
PC-3). Everything is through-hole except the TPS2553 current limiter, which comes
on a small SOT-23 → DIP adapter.

> [!NOTE]
> Not built and tested yet — hardware testing is coming soon. The layout below
> passes an automatic check (every net connected, no hole shared by two nets, no
> wire through a foreign pad, no overlapping parts), but it has not been soldered.

## What you need

- the parts from the [bill of materials](bill-of-materials.md#fanctrl3-lite--modules-on-a-perfboard);
- a soldering iron with a fine tip, thin solder, flux, a multimeter;
- side cutters and a wire stripper;
- the two build documents, generated from the same design:

| Document | What it shows |
|---|---|
| [`FanCtrl3-Lite-perfboard.svg`](../hardware/lite/FanCtrl3-Lite-perfboard.svg) | the component side, and the solder side **mirrored** — the way you see it when you turn the board over — with every wire drawn |
| [`FanCtrl3-Lite-wiring.md`](../hardware/lite/FanCtrl3-Lite-wiring.md) | every part with its holes, every net, every bare wire run and every insulated wire, hole by hole |
| [`FanCtrl3-Lite-schematic.pdf`](../hardware/lite/FanCtrl3-Lite-schematic.pdf) | the circuit |

Lite perfboard: component side and mirrored solder side

## How holes are named

Holes are counted **from the component side**: columns **1–25** from the left,
rows **A–O** from the top, e.g. `E8`. The PC-3 prints its column numbers on the
copper side, so there they run from the right — go by the drawing, not by the
print. Positions A1, A25, O1 and O25 do not exist; the mounting holes are there.

## Wiring

- **Bare wire** runs on the solder side from hole to hole along the grid. Use a
  wire from the MIKROE-2022 kit with its insulation stripped completely; for short
  bridges between neighbouring holes, cut-off resistor leads are enough.
- **Ground** is a bare rail along row O.
- **W wires** (W1, W2, …) are insulated wires on the solder side, soldered straight
  to the pads. They may cross bare wires. 3.3 V and 12 V always use insulated wire.
- The current layout has 44 bare runs (170 steps of 2.54 mm) and 15 insulated
  wires.

## Assembly order

1. **Prepare the current limiter.** Solder the TPS2553DBVR onto the SparkFun
   BOB-00717 adapter so that the chip's **pin 1 lands on adapter hole 1**. Solder
   six header pins (cut from a ZL201-20G strip) into the adapter.
2. **Parts under the Pico first** — they are not reachable once the sockets are in:
   U3 (the adapter, pin 1 at **E8**), C3, and the three resistors that **lie flat**:
   R14 (51 kΩ), R15 and R16 (10 kΩ). Bend their leads at 10.16 mm (4 holes).
   Hold the adapter against its holes before you solder it.
3. **The two Pico sockets** (ZL262-20SG) along rows B and I, columns 1–20 —
   without the Pico.
4. **Standing resistors and transistors.** BC547B with the **flat side towards the
   Pico**, pins C-B-E as in the table.
5. **Connectors:** the three fan headers (pin 1 = GND on the right) and the probe
   terminal.
6. **Capacitors** — mind the polarity of C1 and C2.
7. **The Pololu module** last: it lies flat above the board on its 3-pin header and
   overhangs to the right.
8. **Wiring on the solder side**, net by net, following the tables.
9. **Headers onto the Pico** (two ZL201-20G strips).

## Before you plug in the Pico

> [!IMPORTANT]
> With the Pico **out** of its sockets, check with a multimeter:
> 1. no short between **VBUS (B1)** and **GND (B3)**;
> 2. no short between the **limited 5 V (D22)** and **GND (D23)**;
> 3. no short between **12 V** (K23) and **GND** (K24).
>
> Then plug in the Pico and connect USB. All three fans start at **100 %** until
> the firmware takes over — that is the fail-safe default, not a fault.

Next: [flash the firmware](firmware.md), then [install the host side](host-proxmox.md).

## Regenerating the layout

The perfboard layout, the wiring, the checks, both documents and the enclosure
geometry come from [`hardware/tools/design_lite.py`](../hardware/tools/design_lite.py):

```bash
hardware/tools/build_lite.sh
```

It tries 280 placements of the fan channels and the limiter block, routes each,
and keeps the one with the fewest insulated wires. See
[development.md](development.md).

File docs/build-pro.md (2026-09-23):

# Building FanCtrl3 Pro

A custom two-layer PCB, 90 × 60 mm, designed for **hand soldering**: 0805/1206
passives with hand-solder pads, SOT-23 packages, an SMA diode, no QFN and no parts
with pads underneath.

> [!NOTE]
> The PCB has not been manufactured or tested yet — hardware testing is coming
> soon. The design passes KiCad ERC (0), DRC (0 violations, 0 unconnected pads)
> and the schematic-parity check. If you want the safest path, build the
> [Lite variant](build-lite.md) first: it is the same circuit.

| Top | Bottom |
|---|---|
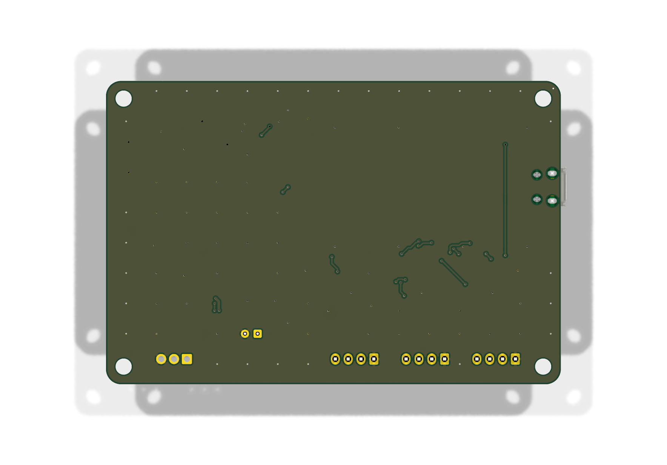
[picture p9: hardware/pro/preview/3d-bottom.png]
Pro PCB, bottom
| Pro PCB, top |  |

## Files

| File | What it is |
|---|---|
| [`fabrication/FanCtrl3-Pro-gerbers.zip`](../hardware/pro/fabrication/FanCtrl3-Pro-gerbers.zip) | Gerbers (copper, mask, paste, silkscreen, outline) + Excellon drill files, ready to upload to a PCB fab |
| [`fabrication/FanCtrl3-Pro-BOM.csv`](../hardware/pro/fabrication/FanCtrl3-Pro-BOM.csv) | bill of materials from KiCad, grouped by footprint, with TME order codes |
| [`FanCtrl3-Pro-schematic.pdf`](../hardware/pro/FanCtrl3-Pro-schematic.pdf) | schematic |
| [`FanCtrl3-Pro.kicad_pro`](../hardware/pro/FanCtrl3-Pro.kicad_pro) | the KiCad 10 project (schematic + PCB) |
| [`FanCtrl3-Pro-erc.rpt`](../hardware/pro/FanCtrl3-Pro-erc.rpt), [`FanCtrl3-Pro-drc.rpt`](../hardware/pro/FanCtrl3-Pro-drc.rpt) | the ERC and DRC reports |

## Ordering the PCB

Upload the Gerber ZIP to any PCB fab. The board uses only standard capabilities:

| | |
|---|---|
| Layers | 2 |
| Size | 90.1 × 60.1 mm |
| Thickness | 1.6 mm |
| Smallest track | 0.25 mm |
| Smallest clearance | 0.2 mm (0.3 mm to copper pours) |
| Vias | 0.3 mm drill, 0.6 mm pad |
| Smallest hole | 0.3 mm |
| Assembly | none — the board is meant to be soldered by hand |

Anything the fab's default options offer (FR-4, HASL, any colour) will do.

## Soldering order

Low parts first, tall parts last:

1. **U2 TPS2553** (SOT-23-6) and **U3 LM27313** (SOT-23-5) — check pin 1 against
   the silkscreen dot; the two chips are the only parts where orientation is easy
   to get wrong. Buying two of each is worth it.
2. **0805 resistors and capacitors**, then the **1206** capacitors C2, C4, C5.
3. **Q1–Q3 2N7002** (SOT-23).
4. **D1 SS14** — the band marks the cathode (towards the 12 V side).
5. **L1** inductor.
6. **The Pico**, flat on the board by its castellated edge. Align it so its micro-USB
   socket overhangs the board edge; tack two opposite corners, check, then solder
   the rest.
7. **C6** 100 µF (polarised), the three **fan headers**, the **probe terminal**.

## Before first power-up

> [!IMPORTANT]
> Before connecting USB, check with a multimeter:
> 1. no short between **VBUS** and **GND**;
> 2. no short between **12 V** and **GND** (on C6);
> 3. no short between the limited **5 V** (the TPS2553 output) and **GND**.
>
> First power-up without fans: the 12 V rail should read **about 12.4 V**. Then
> connect the fans — all three start at **100 %** until the firmware takes over.

Next: [flash the firmware](firmware.md), then [install the host side](host-proxmox.md).

## Regenerating the board

The schematic and the PCB are generated from
[`hardware/tools/design_pro.py`](../hardware/tools/design_pro.py) — do not edit
the `.kicad_sch` or `.kicad_pcb` by hand, the next build overwrites them.

```bash
hardware/tools/build_pro.sh    # schematic -> ERC -> placement -> routing -> DRC
hardware/tools/export_pro.sh   # Gerbers, drill, ZIP, BOM, schematic PDF
```

> [!WARNING]
> The router does not produce the same tracks on every run (every run passes DRC).
> **Always run `export_pro.sh` right after `build_pro.sh`**, otherwise the Gerbers
> no longer match the board file.

See [development.md](development.md).

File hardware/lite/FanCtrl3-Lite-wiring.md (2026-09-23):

# FanCtrl3 Lite — wiring table

Generated by `tools/gen_lite.py` from `tools/design_lite.py` — do not edit by hand.

Holes are counted **from the component side**: columns 1–25 from the left, rows A–O from the top.
The PC-3 board prints its column numbers on the copper side, so there they run from the right.
Corner positions A1, A25, O1 and O25 do not exist (mounting holes sit there).

Drawing: `FanCtrl3-Lite-perfboard.svg` — component side on top, solder side below, mirrored (the way you see the board when you turn it over).

> [!NOTE]
> Hook-up wire: the `MIKROE-2022` jumper wire kit from the bill of materials. W wires are insulated wires from the kit. Bare wire on the solder side is a kit wire with the insulation stripped completely; short bridges between neighbouring holes are cut-off resistor leads.

Assembly order: first the parts that sit under the Pico (U3 on its adapter, C3, R14–R16), then the Pico sockets (without the Pico), resistors and transistors, connectors, capacitors, and the boost module last. Solder-side wires — see the tables below. Plug the Pico in only after checking with a multimeter that there is no short between VBUS (B1) and GND (B3), nor between the limited 5 V rail (D22) and GND (D23).

> [!WARNING]
> BOB-00717 adapter: board 8.6 × 11.7 mm, rows 7.62 mm apart (SparkFun product page). Solder the TPS2553 so that its pin 1 lands on adapter hole 1, and hold the adapter against the U3 holes before you solder it to the perfboard.

## Parts

| Ref | Part | Value | TME | Holes | Notes |
|---|---|---|---|---|---|
| U1 | microcontroller | Raspberry Pi Pico | `SC0915` | B1–B20, I1–I20 | in two ZL262-20SG sockets; ZL201-20G headers soldered to the Pico |
| U2 | 5→12 V boost module | U3V16F12 | `POLOLU-4945` | VIN=F22, GND=G22, VOUT=H22 | module lies flat above the board, overhangs to the right |
| C1 | electrolytic capacitor | 47u 25V | `CE-47/25PHT-Y` | +=D22, -=D23 | converter input |
| C2 | electrolytic capacitor | 100u 25V | `CE-100/25PHT-Y` | +=K23, -=K24 | 12 V rail |
| J4 | screw terminal | DS18B20 | `DG308-2.54-03P` | 1=M24, 2=N24, 3=O24 | probe: red 3V3, yellow DQ, black GND |
| R13 | resistor, standing | 4k7 | `CF1/4W-4K7` | 1=N22, 2=M22 | 1-Wire pull-up |
| J1 | fan header | FAN1 | `MX-47053-1000` | 4=N3, 3=N4, 2=N5, 1=N6 | pin 1 (GND) on the right |
| Q1 | NPN transistor | BC547B | `BC547B-DIO` | C=L3, B=L2, E=L1 | flat side towards the Pico |
| R1 | resistor, standing | 4k7 | `CF1/4W-4K7` | 1=K2, 2=J2 | base resistor |
| R2 | resistor, standing | 10k | `CF1/4W-10K` | 1=N2, 2=M2 | base to GND |
| R3 | resistor, standing | 10k | `CF1/4W-10K` | 1=K4, 2=L4 | in series with the GPIO |
| R4 | resistor, standing | 4k7 | `CF1/4W-4K7` | 1=L5, 2=M5 | tach pull-up to 3V3 |
| J2 | fan header | FAN2 | `MX-47053-1000` | 4=N9, 3=N10, 2=N11, 1=N12 | pin 1 (GND) on the right |
| Q2 | NPN transistor | BC547B | `BC547B-DIO` | C=L9, B=L8, E=L7 | flat side towards the Pico |
| R5 | resistor, standing | 4k7 | `CF1/4W-4K7` | 1=K8, 2=J8 | base resistor |
| R6 | resistor, standing | 10k | `CF1/4W-10K` | 1=N8, 2=M8 | base to GND |
| R7 | resistor, standing | 10k | `CF1/4W-10K` | 1=K10, 2=L10 | in series with the GPIO |
| R8 | resistor, standing | 4k7 | `CF1/4W-4K7` | 1=L11, 2=M11 | tach pull-up to 3V3 |
| J3 | fan header | FAN3 | `MX-47053-1000` | 4=N15, 3=N16, 2=N17, 1=N18 | pin 1 (GND) on the right |
| Q3 | NPN transistor | BC547B | `BC547B-DIO` | C=L15, B=L14, E=L13 | flat side towards the Pico |
| R9 | resistor, standing | 4k7 | `CF1/4W-4K7` | 1=K14, 2=J14 | base resistor |
| R10 | resistor, standing | 10k | `CF1/4W-10K` | 1=N14, 2=M14 | base to GND |
| R11 | resistor, standing | 10k | `CF1/4W-10K` | 1=K16, 2=L16 | in series with the GPIO |
| R12 | resistor, standing | 4k7 | `CF1/4W-4K7` | 1=L17, 2=M17 | tach pull-up to 3V3 |
| U3 | current limiter on an adapter | TPS2553DBV | `TPS2553DBVR` | 1=E8, 2=F8, 3=G8, 4=G11, 5=F11, 6=E11 | on a SparkFun BOB-00717 adapter, 6 pins cut from a ZL201-20G header; chip pin 1 = adapter hole 1 |
| C3 | ceramic capacitor | 100n | `SR205C104KAR` | 1=E6, 2=E5 | at the IN pin |
| R14 | resistor, lying flat (under the Pico) | 51k | `CF1/4W-51K` | 1=F12, 2=F16 | limit 465-570 mA |
| R15 | resistor, lying flat (under the Pico) | 10k | `CF1/4W-10K` | 1=G12, 2=G16 | FAULT pull-up |
| R16 | resistor, lying flat (under the Pico) | 10k | `CF1/4W-10K` | 1=G7, 2=G3 | EN on by default - a dead Pico does not switch the fans off |

## Nets (net → what it connects)

| Net | Pins (hole) |
|---|---|
| `+12V` | U2.VOUT H22, C2.+ K23, J1.2 N5, J2.2 N11, J3.2 N17 |
| `+3V3` | U1.36 B5, J4.1 M24, R13.2 M22, R4.1 L5, R8.1 L11, R12.1 L17, R15.2 G16, R16.2 G3 |
| `+5V_FAN` | U2.VIN F22, C1.+ D22, U3.6 E11 |
| `B1` | Q1.B L2, R1.1 K2, R2.2 M2 |
| `B2` | Q2.B L8, R5.1 K8, R6.2 M8 |
| `B3` | Q3.B L14, R9.1 K14, R10.2 M14 |
| `DQ` | U1.9 I9, J4.2 N24, R13.1 N22 |
| `FAN1_PWM` | J1.4 N3, Q1.C L3 |
| `FAN1_TACH` | J1.3 N4, R3.2 L4, R4.2 M5 |
| `FAN2_PWM` | J2.4 N9, Q2.C L9 |
| `FAN2_TACH` | J2.3 N10, R7.2 L10, R8.2 M11 |
| `FAN3_PWM` | J3.4 N15, Q3.C L15 |
| `FAN3_TACH` | J3.3 N16, R11.2 L16, R12.2 M17 |
| `FAN_EN` | U1.11 I11, U3.3 G8, R16.1 G7 |
| `FAULT` | U1.10 I10, U3.4 G11, R15.1 G12 |
| `GND` | U1.38 B3, U1.3 I3, U1.8 I8, U1.28 B13, U1.13 I13, U1.23 B18, U1.18 I18, U2.GND G22, C1.- D23, C2.- K24, J4.3 O24, J1.1 N6, Q1.E L1, R2.1 N2, J2.1 N12, Q2.E L7, R6.1 N8, J3.1 N18, Q3.E L13, R10.1 N14, U3.2 F8, C3.2 E5, R14.2 F16 |
| `ILIM` | U3.5 F11, R14.1 F12 |
| `PWM1` | U1.1 I1, R1.2 J2 |
| `PWM2` | U1.4 I4, R5.2 J8 |
| `PWM3` | U1.6 I6, R9.2 J14 |
| `TACH1` | U1.2 I2, R3.1 K4 |
| `TACH2` | U1.5 I5, R7.1 K10 |
| `TACH3` | U1.7 I7, R11.1 K16 |
| `VBUS` | U1.40 B1, U3.1 E8, C3.1 E6 |

## Bare wire on the solder side (stripped wire, resistor lead or a solder trail)

Each row is one straight run from hole to hole, net by net.

| # | Net | From | To |
|---|---|---|---|
| 1 | `GND` | O2 | O24 (J4.3) |
| 2 | `ILIM` | F11 (U3.5) | F12 (R14.1) |
| 3 | `VBUS` | B1 (U1.40) | C1 |
| 4 | `VBUS` | C1 | C6 |
| 5 | `VBUS` | C6 | E6 (C3.1) |
| 6 | `VBUS` | E6 (C3.1) | E8 (U3.1) |
| 7 | `+5V_FAN` | F22 (U2.VIN) | D22 (C1.+) |
| 8 | `+5V_FAN` | E22 | E11 (U3.6) |
| 9 | `FAULT` | I10 (U1.10) | G10 |
| 10 | `FAULT` | G10 | G11 (U3.4) |
| 11 | `FAULT` | G11 (U3.4) | G12 (R15.1) |
| 12 | `FAN_EN` | G8 (U3.3) | G7 (R16.1) |
| 13 | `DQ` | I9 (U1.9) | C9 |
| 14 | `DQ` | C9 | C25 |
| 15 | `DQ` | C25 | N25 |
| 16 | `DQ` | N25 | N24 (J4.2) |
| 17 | `DQ` | N24 (J4.2) | N22 (R13.1) |
| 18 | `GND` | I13 (U1.13) | L13 (Q3.E) |
| 19 | `GND` | L13 (Q3.E) | N13 |
| 20 | `GND` | N13 | N12 (J2.1) |
| 21 | `GND` | N13 | N14 (R10.1) |
| 22 | `GND` | I18 (U1.18) | N18 (J3.1) |
| 23 | `GND` | I18 (U1.18) | F18 |
| 24 | `GND` | F18 | F16 (R14.2) |
| 25 | `GND` | G18 | G22 (U2.GND) |
| 26 | `GND` | G22 (U2.GND) | G23 |
| 27 | `GND` | G23 | D23 (C1.-) |
| 28 | `GND` | G23 | G24 |
| 29 | `GND` | G24 | K24 (C2.-) |
| 30 | `GND` | N12 (J2.1) | O12 |
| 31 | `GND` | O12 | O8 |
| 32 | `GND` | O8 | N8 (R6.1) |
| 33 | `GND` | O2 | N2 (R2.1) |
| 34 | `GND` | O6 | N6 (J1.1) |
| 35 | `GND` | O7 | L7 (Q2.E) |
| 36 | `GND` | N2 (R2.1) | N1 |
| 37 | `GND` | N1 | L1 (Q1.E) |
| 38 | `GND` | I3 (U1.3) | H3 |
| 39 | `GND` | H3 | H5 |
| 40 | `GND` | H5 | E5 (C3.2) |
| 41 | `GND` | F5 | F8 (U3.2) |
| 42 | `FAN2_TACH` | N10 (J2.3) | L10 (R7.2) |
| 43 | `FAN2_TACH` | M10 | M11 (R8.2) |
| 44 | `FAN2_PWM` | N9 (J2.4) | L9 (Q2.C) |
| 45 | `FAN1_PWM` | N3 (J1.4) | L3 (Q1.C) |
| 46 | `B2` | L8 (Q2.B) | K8 (R5.1) |
| 47 | `B2` | L8 (Q2.B) | M8 (R6.2) |
| 48 | `PWM2` | I4 (U1.4) | J4 |
| 49 | `PWM2` | J4 | J8 (R5.2) |
| 50 | `B1` | L2 (Q1.B) | K2 (R1.1) |
| 51 | `B1` | L2 (Q1.B) | M2 (R2.2) |
| 52 | `B3` | L14 (Q3.B) | K14 (R9.1) |
| 53 | `B3` | L14 (Q3.B) | M14 (R10.2) |
| 54 | `PWM1` | I1 (U1.1) | J1 |
| 55 | `PWM1` | J1 | J2 (R1.2) |
| 56 | `FAN3_PWM` | N15 (J3.4) | L15 (Q3.C) |
| 57 | `FAN3_TACH` | N16 (J3.3) | L16 (R11.2) |
| 58 | `FAN3_TACH` | M16 | M17 (R12.2) |
| 59 | `FAN1_TACH` | N4 (J1.3) | L4 (R3.2) |
| 60 | `FAN1_TACH` | M4 | M5 (R4.2) |
| 61 | `+3V3` | M22 (R13.2) | M24 (J4.1) |

## Insulated wires (solder side)

Insulated wire from the MIKROE-2022 kit on the solder side, ends soldered straight to the pads. It may cross bare wires.

| Wire | Net | From | To | Length |
|---|---|---|---|---|
| W1 | `FAN_EN` | I11 (U1.11) | G8 (U3.3) | ≈ 9 mm |
| W2 | `TACH3` | I7 (U1.7) | K16 (R11.1) | ≈ 23 mm |
| W3 | `PWM3` | I6 (U1.6) | J14 (R9.2) | ≈ 20 mm |
| W4 | `TACH1` | I2 (U1.2) | K4 (R3.1) | ≈ 7 mm |
| W5 | `TACH2` | I5 (U1.5) | K10 (R7.1) | ≈ 14 mm |
| W6 | `+12V` | H22 (U2.VOUT) | K23 (C2.+) | ≈ 8 mm |
| W7 | `+12V` | K23 (C2.+) | N17 (J3.2) | ≈ 17 mm |
| W8 | `+12V` | N17 (J3.2) | N11 (J2.2) | ≈ 15 mm |
| W9 | `+12V` | N11 (J2.2) | N5 (J1.2) | ≈ 15 mm |
| W10 | `+3V3` | B5 (U1.36) | G3 (R16.2) | ≈ 14 mm |
| W11 | `+3V3` | G3 (R16.2) | L5 (R4.1) | ≈ 14 mm |
| W12 | `+3V3` | L5 (R4.1) | L11 (R8.1) | ≈ 15 mm |
| W13 | `+3V3` | L11 (R8.1) | L17 (R12.1) | ≈ 15 mm |
| W14 | `+3V3` | L17 (R12.1) | G16 (R15.2) | ≈ 13 mm |
| W15 | `+3V3` | L17 (R12.1) | M22 (R13.2) | ≈ 13 mm |

## Check

- parts: 29, nets: 24
- bare wire on the solder side: 44 runs, 170 steps of 2.54 mm
- insulated wires: 15
- problems found by the checker: 0

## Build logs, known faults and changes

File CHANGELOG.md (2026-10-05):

# Changelog

All notable changes to FanCtrl3. Versions follow [Semantic Versioning](https://semver.org/).
Changes to the documentation alone go into an `Unreleased` section and ship with the
next release (see [CONTRIBUTING.md](CONTRIBUTING.md#versions)).

## [1.1.0] — 2026-10-05

### Added
- AMD CPUs: the host daemon reads `k10temp` and `zenpower` (`Tdie`, else `Tctl`)
  besides Intel `coretemp`, and logs which sensor it uses.
- GitHub Actions runs `tests/run_all.sh` on every push and pull request.
- `tests/test_host.py`: host-side tests that need no controller.
- Issue templates for bug reports and build reports.

### Fixed
- `SET`, `MIN` and `CURVE` accepted `nan` and `inf`. A fan at `nan` duty broke
  `STATUS` and made every control step fail (`ERR INTERNAL`, fans at 100 %). They now
  reply `ERR ARGS`, and a saved configuration with such values falls back to the
  defaults.
- Hosts with more than one CPU package: the hottest package is used, not the first.
- The daemon no longer waits forever for a socket client that connects and sends
  nothing (which stopped the temperature updates and sent the controller to failsafe).
- `fanctl send` prints `no reply from the controller` instead of `None`, and every
  command without a daemon reports a missing device in one line instead of a
  traceback.
- The firmware comment on the LED patterns now matches the code.

### Changed
- The build, flash and test scripts run in `bash` instead of `zsh`, which Debian and
  Proxmox do not install by default.
- The daemon logs a missing CPU temperature once, not at every interval.

## [1.0.11] — 2026-09-23

### Documentation
- README: the Sponsor badge really is twice as large now — GitHub ignores the
  `height` attribute (it forces `height: auto`), so the size is set with `width`.

## [1.0.10] — 2026-09-23

### Documentation
- README: the Sponsor badge is twice as large, on its own line below the other badges.

## [1.0.9] — 2026-09-23

### Documentation
- GitHub Sponsors: `.github/FUNDING.yml`, a badge and a "Support the project"
  section in the README.

## [1.0.8] — 2026-09-23

### Documentation
- README: what is verified without hardware, what is not tested yet, known
  issues; note that FanCtrl3 is a hobby project developed in spare time.

## [1.0.7] — 2026-09-23

### Fixed
- `fanctl calibrate` without a running daemon: once the controller was in
  failsafe it forced every fan to 100 %, the calibration took minutes and stored
  a wrong minimum. It now refuses to start in failsafe and stops, keeping the old
  minimum, when the controller does not follow the requested duty.
- `fanctl calibrate` sent `SAVE` even when nothing was measured, which also stored
  any other unsaved changes. It now saves only when a new minimum was measured.

## [1.0.6] — 2026-09-23

### Fixed
- `SAVE` replied `OK SAVE` before the file was written, so a failed write
  looked like a success (it only showed up as `ERR INTERNAL`). The reply now
  comes after the write: `OK SAVE`, or `ERR SAVE <reason>`.

## [1.0.5] — 2026-09-23

### Fixed
- A saved configuration with `min_duty` or `enabled` of the wrong length (or with
  non-numeric entries) crashed the control step. Such values are now ignored and
  the default is kept.

## [1.0.4] — 2026-09-23

### Fixed
- Ambient alarms: falling from the critical to the warning level sent
  `INFO AMB OK` followed by `ALARM AMB HIGH`, and falling from the warning level
  to normal sent nothing. Every change of level now sends exactly one line
  (`ALARM AMB HIGH`, `ALARM AMB CRIT`, `INFO AMB HIGH`, `INFO AMB OK`).
- The ambient levels have a 1.0 °C hysteresis (`amb_hyst`), so a reading that
  hovers around a threshold no longer makes the fans and the alarms flap.

## [1.0.3] — 2026-09-23

### Fixed
- A daemon restarted on a host without a readable CPU temperature left the fans at
  rest duty (20 %) for good, because the `BYE` of the previous run put the
  controller in rest mode, which has no timeout. The daemon now sends the new
  `HELLO` command whenever it connects: the controller leaves rest and goes to
  failsafe unless a `TEMP` follows.

## [1.0.2] — 2026-09-23

### Fixed
- `STATUS` right after `BYE` reported the previous mode until the next control
  step; it now reports `rest` at once, the same way `TEMP` reports `auto`.

## [1.0.1] — 2026-09-23

### Fixed
- `SERVICE` no longer drops to the REPL with the watchdog still running (the
  RP2040 watchdog cannot be stopped, so the board reset about 8 s later). It now
  resets into a service mode — fans at 100 %, REPL, no watchdog — until the next
  reset.

## [1.0.0] — 2026-09-23

First complete design. **Not yet tested on hardware** — hardware testing is coming soon.

### Hardware
- FanCtrl3 Pro: 2-layer 90 × 60 mm PCB for hand soldering — Raspberry Pi Pico,
  TPS2553 current limiter (465–570 mA), LM27313 5 V → 12.4 V boost, three 2N7002
  open-drain PWM outputs, tach inputs, DS18B20 probe terminal. ERC 0, DRC 0,
  schematic parity 0. Gerbers, drill files and BOM.
- FanCtrl3 Lite: the same circuit from modules on an SCI PC-3 perfboard — Pololu
  U3V16F12, BC547B open-collector outputs, TPS2553 on a SparkFun BOB-00717 adapter
  under the Pico. Generated layout, wiring drawing and wiring table; ERC 0.
- Parametric OpenSCAD enclosure for both variants, STL files, collision check.

### Firmware
- MicroPython for the Pico: 25 kHz PWM, tach on interrupts, DS18B20, fan curve with
  hysteresis and ramping, per-fan minimum duty, failsafe on stale temperature,
  rest on host shutdown, ambient override, stall and overload alarms, hardware
  watchdog, text protocol over USB CDC.

### Host
- `fanctl` for Proxmox VE: daemon feeding the CPU package temperature (coretemp),
  `status`, `send`, `calibrate`; udev rule, systemd unit, installer.

### Tests
- Control logic under CPython and MicroPython, firmware smoke test on stubbed
  hardware, end-to-end test of the host side against a simulated controller.

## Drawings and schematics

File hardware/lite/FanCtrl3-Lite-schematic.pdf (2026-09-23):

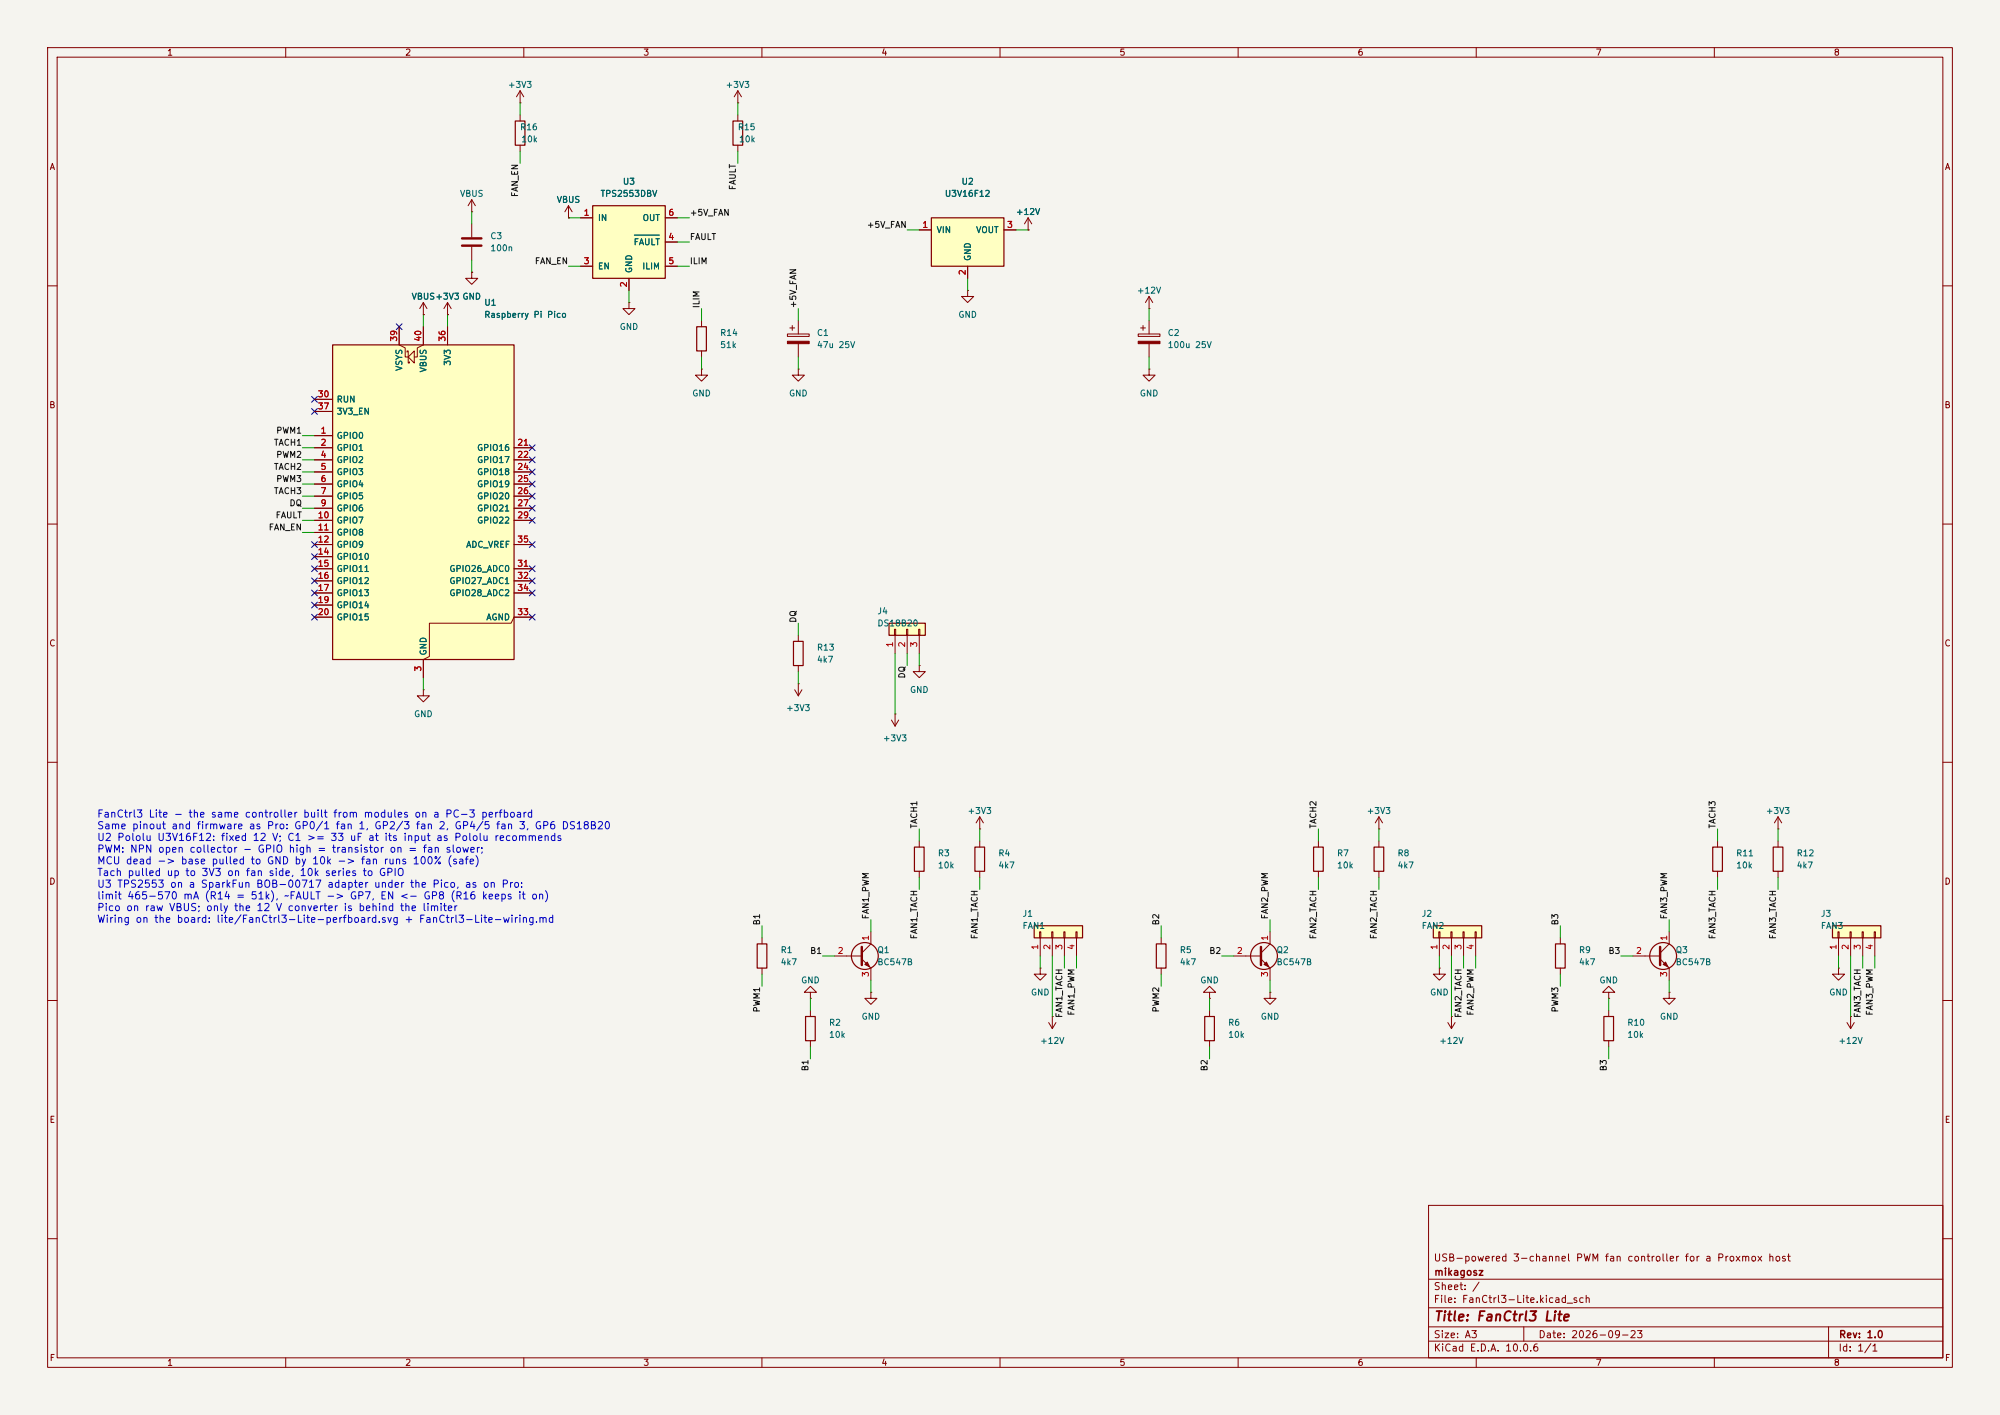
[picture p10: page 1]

FanCtrl3 Lite - the same controller built from modules on a PC-3 perfboard
Same pinout and firmware as Pro: GP0/1 fan 1, GP2/3 fan 2, GP4/5 fan 3, GP6 DS18B20
U2 Pololu U3V16F12: fixed 12 V; C1 >= 33 uF at its input as Pololu recommends
PWM: NPN open collector - GPIO high = transistor on = fan slower;
MCU dead -> base pulled to GND by 10k -> fan runs 100% (safe)
Tach pulled up to 3V3 on fan side, 10k series to GPIO
U3 TPS2553 on a SparkFun BOB-00717 adapter under the Pico, as on Pro:
limit 465-570 mA (R14 = 51k), ~FAULT -> GP7, EN <- GP8 (R16 keeps it on)
Pico on raw VBUS; only the 12 V converter is behind the limiter
Wiring on the board: lite/FanCtrl3-Lite-perfboard.svg + FanCtrl3-Lite-wiring.md

USB-powered 3-channel PWM fan controller for a Proxmox host R3

Size: A3 | Rev: 1.0 | F Date: 2026-09-23
KiCad E.D.A. 10.0.6 | Id: 1/1

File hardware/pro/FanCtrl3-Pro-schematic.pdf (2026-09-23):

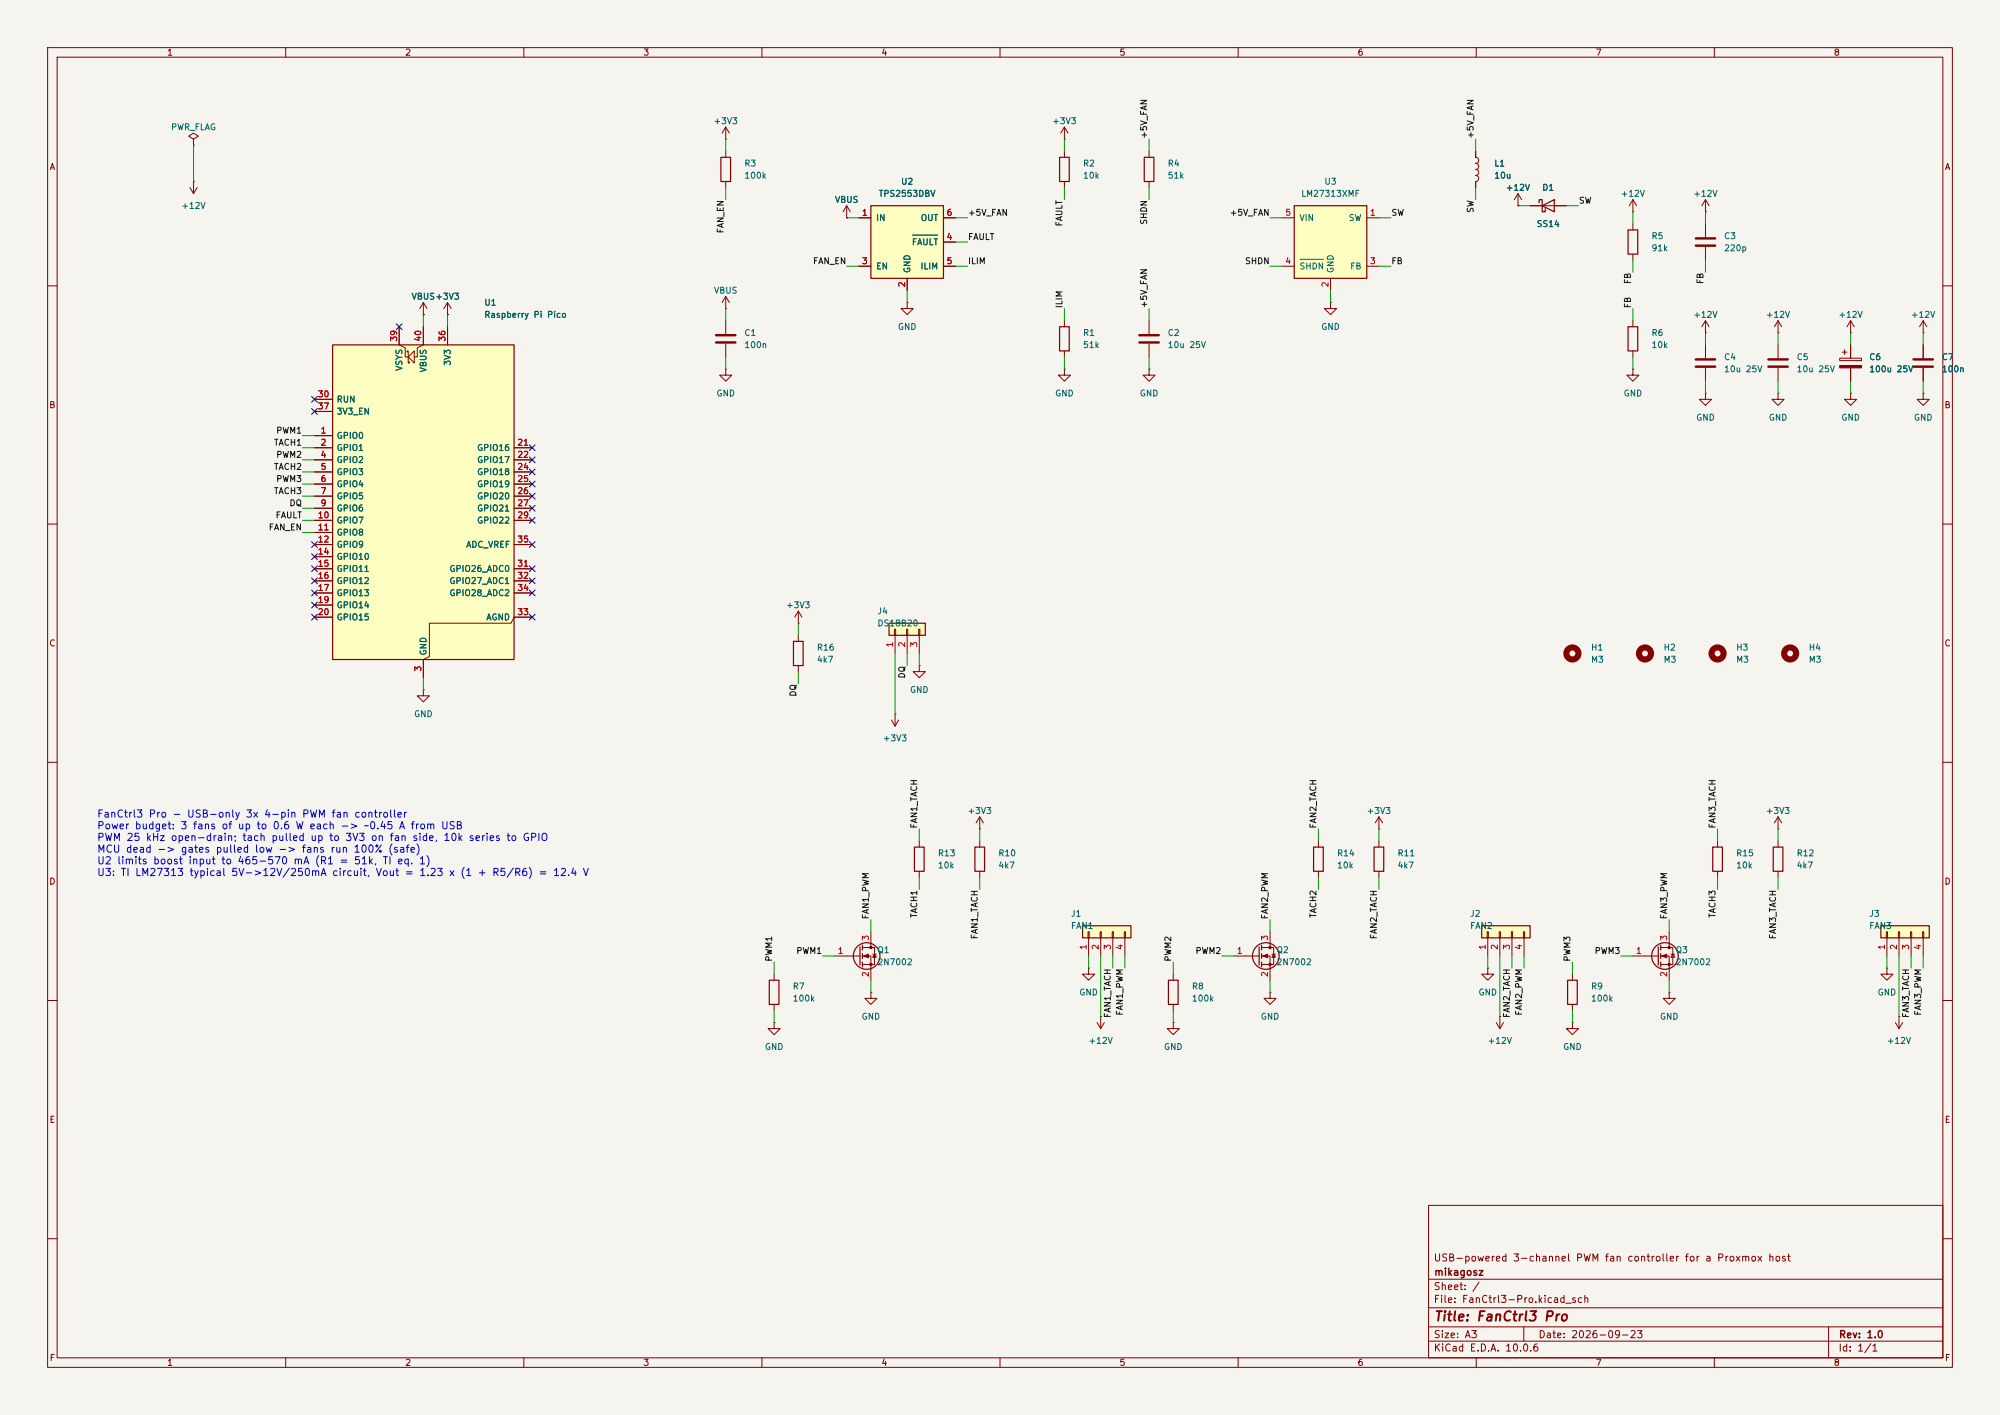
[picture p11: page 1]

FanCtrl3 Pro - USB-only 3x 4-pin PWM fan controller
Power budget: 3 fans of up to 0.6 W each -> ~0.45 A from USB
PWM 25 kHz open-drain; tach pulled up to 3V3 on fan side, 10k series to GPIO
MCU dead -> gates pulled low -> fans run 100% (safe)
U2 limits boost input to 465-570 mA (R1 = 51k, TI eq. 1)
U3: TI LM27313 typical 5V->12V/250mA circuit, Vout = 1.23 x (1 + R5/R6) = 12.4 V

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

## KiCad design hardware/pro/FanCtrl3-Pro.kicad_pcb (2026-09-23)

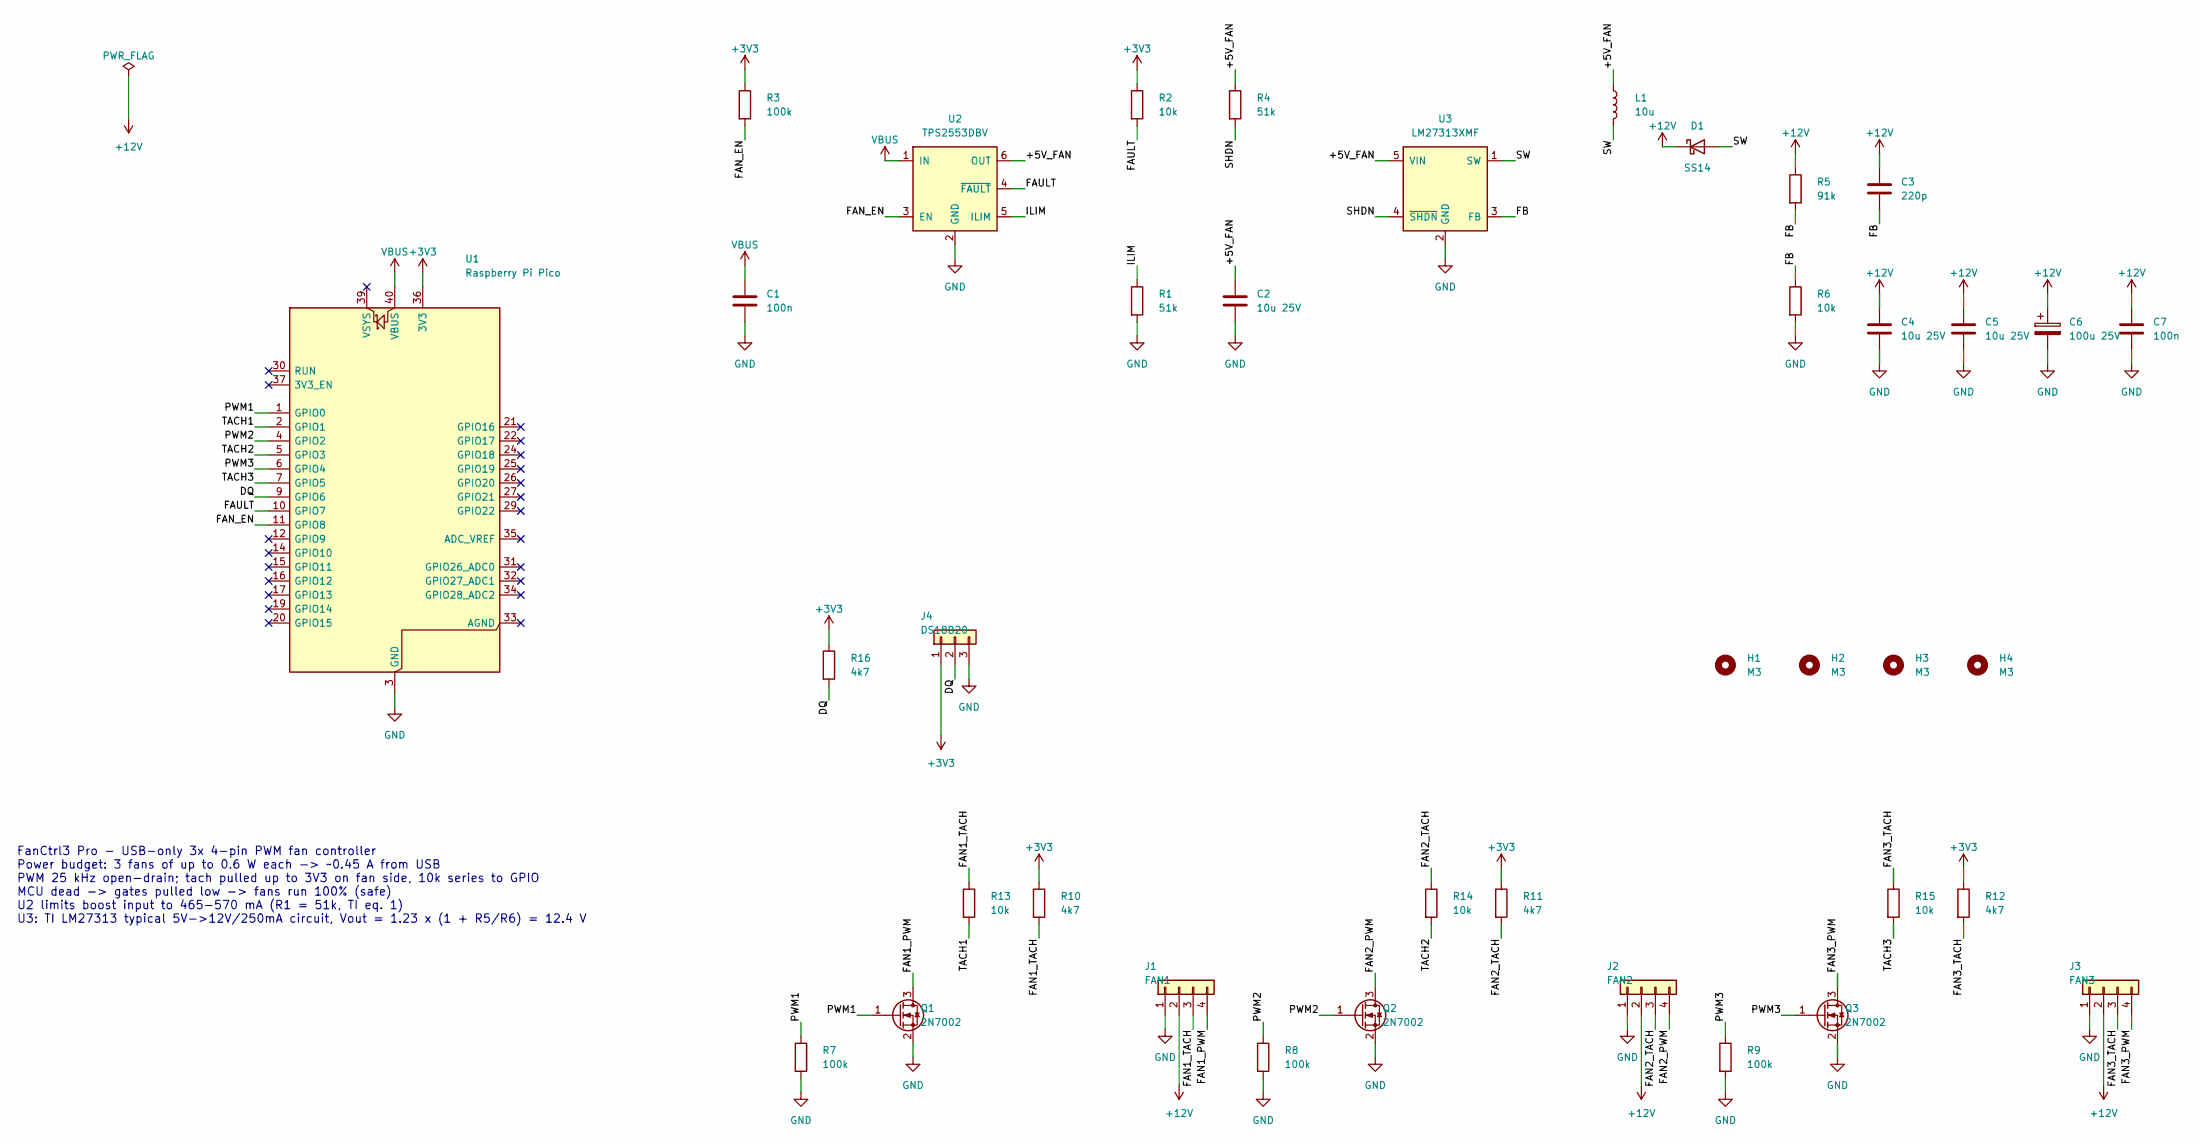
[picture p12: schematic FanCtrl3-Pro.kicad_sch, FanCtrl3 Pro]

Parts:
C1, C7: 100n; C_0805_2012Metric_Pad1.18x1.45mm_HandSolder
C2, C4, C5: 10u 25V; C_1206_3216Metric_Pad1.33x1.80mm_HandSolder
C3: 220p; C_0805_2012Metric_Pad1.18x1.45mm_HandSolder
C6: 100u 25V; CP_Radial_D6.3mm_P2.50mm
D1: SS14; D_SMA_Handsoldering
H1, H2, H3, H4: M3; MountingHole_3.2mm_M3
J1: FAN1; Molex_KK-254_AE-6410-04A_1x04_P2.54mm_Vertical
J2: FAN2; Molex_KK-254_AE-6410-04A_1x04_P2.54mm_Vertical
J3: FAN3; Molex_KK-254_AE-6410-04A_1x04_P2.54mm_Vertical
J4: DS18B20; TerminalBlock_Xinya_XY308-2.54-3P_1x03_P2.54mm_Horizontal
L1: 10u; L_Changjiang_FNR5040S
Q1, Q2, Q3: 2N7002; SOT-23_Handsoldering
R1, R4: 51k; R_0805_2012Metric_Pad1.20x1.40mm_HandSolder
R2, R6, R13, R14, R15: 10k; R_0805_2012Metric_Pad1.20x1.40mm_HandSolder
R3, R7, R8, R9: 100k; R_0805_2012Metric_Pad1.20x1.40mm_HandSolder
R5: 91k; R_0805_2012Metric_Pad1.20x1.40mm_HandSolder
R10, R11, R12, R16: 4k7; R_0805_2012Metric_Pad1.20x1.40mm_HandSolder
U1: Raspberry Pi Pico; RaspberryPi_Pico_SMD_HandSolder
U2: TPS2553DBV; SOT-23-6_Handsoldering
U3: LM27313XMF; SOT-23-5_HandSoldering

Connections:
+3V3: J4.1, R2.1, R3.1, R10.1, R11.1, R12.1, R16.1, U1.36 (3V3)
+12V: C3.1, C4.1, C5.1, C6.1, C7.1, D1.1 (K), J1.2, J2.2, J3.2, R5.1
/+5V_FAN: C2.1, L1.1, R4.1, U2.6 (OUT), U3.5 (VIN)
/DQ: J4.2, R16.2, U1.9 (GPIO6)
/FAN1_PWM: J1.4, Q1.3 (D)
/FAN1_TACH: J1.3, R10.2, R13.1
/FAN2_PWM: J2.4, Q2.3 (D)
/FAN2_TACH: J2.3, R11.2, R14.1
/FAN3_PWM: J3.4, Q3.3 (D)
/FAN3_TACH: J3.3, R12.2, R15.1
/FAN_EN: R3.2, U1.11 (GPIO8), U2.3 (EN)
/FAULT: R2.2, U1.10 (GPIO7), U2.4 (~FAULT)
/FB: C3.2, R5.2, R6.1, U3.3 (FB)
/ILIM: R1.1, U2.5 (ILIM)
/PWM1: Q1.1 (G), R7.1, U1.1 (GPIO0)
/PWM2: Q2.1 (G), R8.1, U1.4 (GPIO2)
/PWM3: Q3.1 (G), R9.1, U1.6 (GPIO4)
/SHDN: R4.2, U3.4 (~SHDN)
/SW: D1.2 (A), L1.2, U3.1 (SW)
/TACH1: R13.2, U1.2 (GPIO1)
/TACH2: R14.2, U1.5 (GPIO3)
/TACH3: R15.2, U1.7 (GPIO5)
GND: C1.2, C2.2, C4.2, C5.2, C6.2, C7.2, J1.1, J2.1, J3.1, J4.3, Q1.2 (S), Q2.2 (S), Q3.2 (S), R1.2, R6.2, R7.2, R8.2, R9.2, U1.3 (GND), U1.8 (GND), U1.13 (GND), U1.18 (GND), U1.23 (GND), U1.28 (GND), U1.38 (GND), U2.2 (GND), U3.2 (GND)
VBUS: C1.1, U1.40 (VBUS), U2.1 (IN)

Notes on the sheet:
FanCtrl3 Pro - USB-only 3x 4-pin PWM fan controller Power budget: 3 fans of up to 0.6 W each -> ~0.45 A from USB PWM 25 kHz open-drain; tach pulled up to 3V3 on fan side, 10k series to GPIO MCU dead -> gates pulled low -> fans run 100% (safe) U2 limits boost input to 465-570 mA (R1 = 51k, TI eq. 1)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

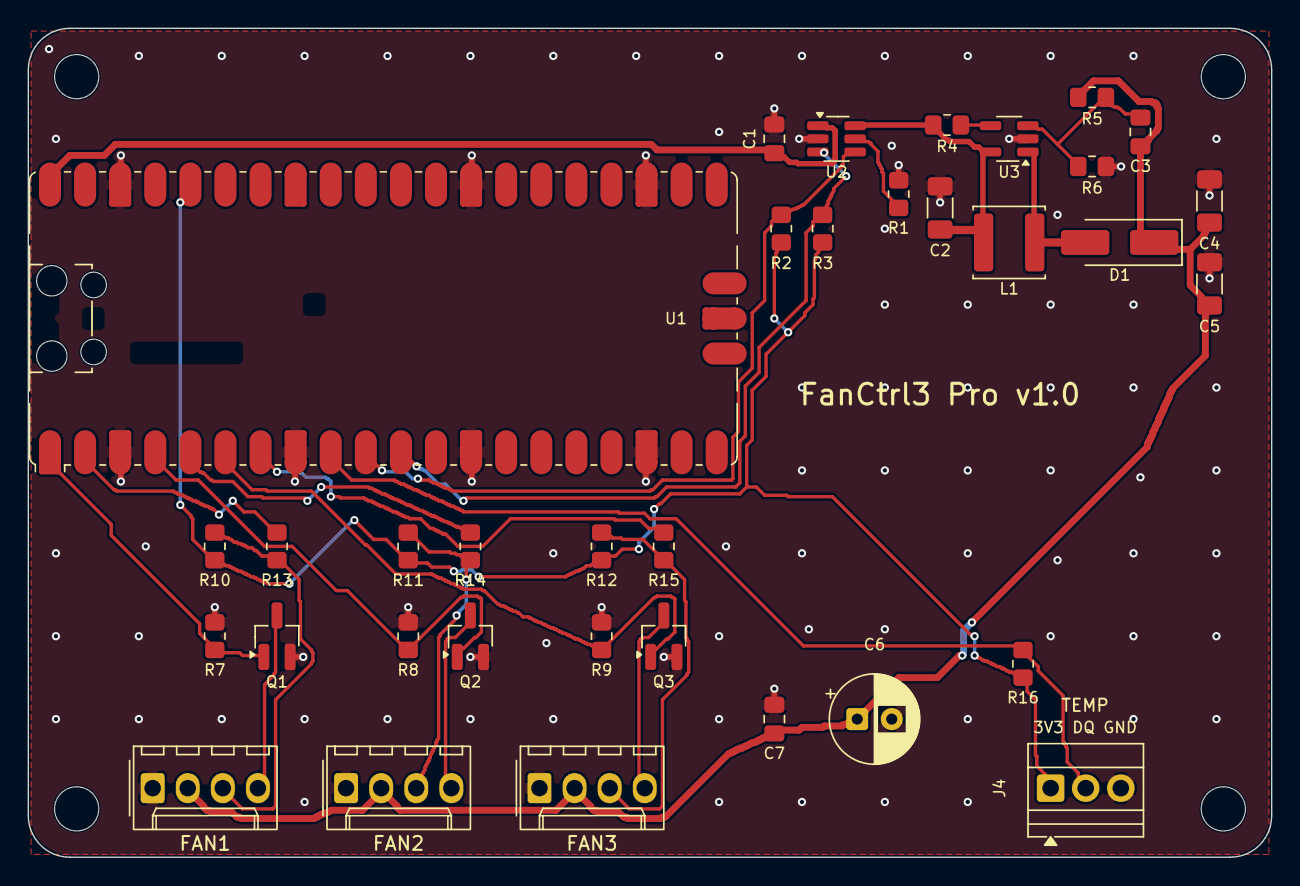
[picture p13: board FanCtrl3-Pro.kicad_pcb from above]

Board: 2 copper layers, 90.0 x 60.0 mm, 39 parts (0 on the bottom side), 24 nets.

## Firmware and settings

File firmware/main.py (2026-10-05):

"""FanCtrl3 firmware for the Raspberry Pi Pico (MicroPython, rp2 port).

Hardware glue only - all decisions are in logic.py.

Pinout (same on Pro and Lite):
  GP0/GP2/GP4  PWM to fan 1/2/3 (25 kHz, inverted: pin high = transistor on = fan slower)
  GP1/GP3/GP5  tach of fan 1/2/3 (2 pulses per revolution)
  GP6          DS18B20 ambient probe (1-Wire)
  GP7          TPS2553 FAULT, active low (both; Lite has the TPS2553 on an adapter)
  GP8          TPS2553 EN - driven high, fans powered (pulled up on the board too)
  LED          status, every 2 s: one short flash = auto, two = start/rest;
               fast blinking (125 ms on/off) = failsafe

Protocol: text lines over USB CDC, see logic.Controller.command.

Nothing blocks: stdin is polled, tach pulses are counted in IRQs, and the control
step runs every second from the main loop.
Ctrl-C from the host is ignored (micropython.kbd_intr(-1)), otherwise one stray
byte would stop the program and freeze the fans. Service access: the first
SERVICE_WINDOW_MS after power-up still accept Ctrl-C (mpremote), or send SERVICE:
the board resets into service mode - fans at 100 %, REPL, no watchdog - until the
next reset. A hardware watchdog restarts the board if the loop ever hangs.
"""
import json
import sys
import time

import machine
import micropython
import select
from machine import PWM, Pin

import logic

# relative to the working directory, which is the filesystem root on the Pico
CONFIG_FILE = "fanctrl3.json"
SERVICE_FLAG = "fanctrl3.service"
SERVICE_WINDOW_MS = 3000
PWM_FREQ = 25000
PWM_PINS = (0, 2, 4)
TACH_PINS = (1, 3, 5)
PULSES_PER_REV = 2
STEP_MS = 1000
DS_CONVERT_MS = 800        # DS18B20 needs 750 ms at 12 bit
DS_RESCAN_MS = 30000

# --- hardware -------------------------------------------------------------------------
pwms = []
for g in PWM_PINS:
    p = PWM(Pin(g))
    p.freq(PWM_FREQ)
    p.duty_u16(0)          # pin low = transistor off = fan at 100 % until we decide
    pwms.append(p)

counts = [0, 0, 0]


def _tach_irq(i):
    def handler(pin):
        counts[i] += 1
    return handler


for i, g in enumerate(TACH_PINS):
    Pin(g, Pin.IN, Pin.PULL_UP).irq(trigger=Pin.IRQ_FALLING, handler=_tach_irq(i))

fault_pin = Pin(7, Pin.IN, Pin.PULL_UP)
en_pin = Pin(8, Pin.OUT, value=1)
led = Pin("LED", Pin.OUT, value=0)


def set_duty(i, pct):
    # open collector / open drain: the fan sees high while our pin is LOW
    pwms[i].duty_u16(int((100.0 - pct) * 65535 / 100))


class Ambient:
    """DS18B20 without blocking: start a conversion, read it on a later step."""

    def __init__(self):
        self.ds = None
        self.rom = None
        self.started = None
        self.value = None
        self.last_scan = None
        try:
            import onewire
            import ds18x20
            self.ds = ds18x20.DS18X20(onewire.OneWire(Pin(6)))
        except Exception:
            self.ds = None

    def poll(self, now):
        if self.ds is None:
            return None
        try:
            if self.rom is None:
                if self.last_scan is None or now - self.last_scan >= DS_RESCAN_MS:
                    self.last_scan = now
                    roms = self.ds.scan()
                    self.rom = roms[0] if roms else None
                return None
            if self.started is None:
                self.ds.convert_temp()
                self.started = now
            elif now - self.started >= DS_CONVERT_MS:
                t = self.ds.read_temp(self.rom)
                self.started = None
                # 85.0 is the power-on value, not a reading
                self.value = t if t is not None and -40 < t < 85 else None
        except Exception:
            self.rom = None
            self.started = None
            self.value = None
        return self.value


# --- config -----------------------------------------------------------------------------
def load_config():
    try:
        with open(CONFIG_FILE) as f:
            return json.load(f)
    except Exception:
        return None


def save_config(cfg):
    tmp = CONFIG_FILE + ".tmp"
    with open(tmp, "w") as f:
        json.dump(cfg, f)
    import os
    os.rename(tmp, CONFIG_FILE)


# --- clock without wrap-around --------------------------------------------------------------
_ms = 0
_last_ticks = time.ticks_ms()


def now_ms():
    global _ms, _last_ticks
    t = time.ticks_ms()
    _ms += time.ticks_diff(t, _last_ticks)
    _last_ticks = t
    return _ms


def write(line):
    try:
        sys.stdout.write(line + "\n")
    except Exception:
        pass


def blink(mode, now):
    phase = now % 2000
    if mode == "failsafe":
        on = (now % 250) < 125
    elif mode == "auto":
        on = phase < 60
    else:
        on = phase < 60 or 200 <= phase < 260
    led.value(1 if on else 0)


def service_boot():
    """Boot after SERVICE: fans at 100 %, REPL, no watchdog. True if this is one.

    The RP2040 watchdog cannot be stopped once started, so SERVICE does not drop
    to the REPL from the running program - it leaves a flag and resets instead."""
    import os
    try:
        os.remove(SERVICE_FLAG)
    except OSError:
        return False
    for i in range(logic.NFANS):
        set_duty(i, 100)
    en_pin.value(1)
    led.value(1)
    write("FanCtrl3 %s service mode: REPL, fans at 100%%, reset to resume" % logic.VERSION)
    return True


def main():
    if service_boot():
        return
    ctl = logic.Controller(load_config(), now_ms())
    for i in range(logic.NFANS):
        set_duty(i, ctl.duty[i])
    amb = Ambient()

    # service window: Ctrl-C still works for SERVICE_WINDOW_MS after power-up
    write("FanCtrl3 %s start" % logic.VERSION)
    while now_ms() < SERVICE_WINDOW_MS:
        time.sleep_ms(50)
    micropython.kbd_intr(-1)
    wdt = machine.WDT(timeout=8000)

    poll = select.poll()
    poll.register(sys.stdin, select.POLLIN)
    buf = ""
    next_step = now_ms()
    last_counts_ms = now_ms()

    while True:
        wdt.feed()
        try:
            for _ in poll.poll(20):
                ch = sys.stdin.read(1)
                if ch in ("\n", "\r"):
                    if buf:
                        for line in ctl.command(buf, now_ms()):
                            write(line)
                        buf = ""
                elif len(buf) < 120:
                    buf += ch
            if ctl.save_requested:
                try:
                    save_config(ctl.cfg)
                    replies = ctl.saved()
                except Exception as e:
                    replies = ctl.saved(str(e) or type(e).__name__)
                for line in replies:
                    write(line)
            if ctl.service_requested:
                for i in range(logic.NFANS):
                    set_duty(i, 100)
                with open(SERVICE_FLAG, "w") as f:
                    f.write("1")
                write("SERVICE: resetting into service mode")
                machine.reset()

            now = now_ms()
            a = amb.poll(now)
            if now >= next_step:
                next_step += STEP_MS
                dt = (now - last_counts_ms) / 1000.0
                last_counts_ms = now
                irq_state = machine.disable_irq()
                c = list(counts)
                for i in range(3):
                    counts[i] = 0
                machine.enable_irq(irq_state)
                rpm = [int(n * 60 / PULSES_PER_REV / dt) if dt > 0 else 0 for n in c]
                for line in ctl.tick(now, rpm, a, fault_pin.value() == 0):
                    write(line)
                for i in range(logic.NFANS):
                    set_duty(i, ctl.duty[i])
            blink(ctl.mode, now)
        except Exception as e:
            # never leave the loop on an error - the fans must keep being driven
            write("ERR INTERNAL %s" % e)
            for i in range(logic.NFANS):
                set_duty(i, 100)


main()

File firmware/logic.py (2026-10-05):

"""FanCtrl3 control logic - no hardware here, runs under MicroPython and CPython.

main.py (on the Pico) and sim/pico_sim.py (on a computer) feed it the clock,
fan speeds, ambient temperature and command lines; it answers with the duty for
each fan and the lines to send back to the host.

Safety rules:
- the curve runs here, not on the host - a host restart does not stop cooling;
- no TEMP for STALE_S seconds -> 100 % (not knowing the CPU is no reason to slow down);
- BYE (clean host shutdown) -> REST_DUTY instead of 100 %;
- ambient (DS18B20) above AMB_WARN / AMB_CRIT raises the fans whatever the host says;
- MIN_DUTY per fan, so a fan never stalls below its starting duty;
- hysteresis + ramp, so the fans do not "pump" every second.

Duty values are percent of fan speed (100 = full). main.py inverts them for the
open-collector / open-drain output.
"""

VERSION = "1.1.0"
NFANS = 3

DEFAULTS = {
    "curve": [[35, 20], [50, 35], [65, 60], [75, 100]],  # CPU degC -> duty %
    "min_duty": [20, 20, 20],     # per fan; measure with `fanctl calibrate`
    "enabled": [1, 1, 1],         # 0 = no fan on that header (no stall alarms)
    "hyst": 3.0,                  # degC the CPU must fall before the fans slow down
    "ramp_up": 10.0,              # % per second
    "ramp_down": 2.0,             # % per second
    "stale_s": 30,                # no TEMP this long -> 100 %
    "start_duty": 60,             # after power-up, before the first TEMP
    "rest_duty": 20,              # after BYE
    "amb_warn": 40.0,             # ambient degC -> at least amb_warn_duty
    "amb_warn_duty": 60,
    "amb_crit": 45.0,             # ambient degC -> 100 %
    "amb_hyst": 1.0,              # degC below a threshold before its level clears
    "stall_duty": 30,             # a fan this fast with 0 rpm ...
    "stall_s": 5,                 # ... for this long -> ALARM FANn STALL
}

MODES = ("start", "auto", "rest", "failsafe")


PER_FAN = ("min_duty", "enabled")  # one number per fan header


def finite(x):
    """A real number: not a bool, not nan, not +-inf (all three pass float())."""
    return (isinstance(x, (int, float)) and not isinstance(x, bool)
            and -1e300 < x < 1e300)


def number(s):
    """float(s) for a command argument; ValueError for nan and inf too."""
    v = float(s)
    if not finite(v):
        raise ValueError
    return v


def per_fan_ok(v):
    return isinstance(v, list) and len(v) == NFANS and all(finite(x) for x in v)


def merge_config(saved):
    """Defaults overlaid with a saved config; anything malformed falls back."""
    cfg = {}
    for k, v in DEFAULTS.items():
        cfg[k] = list(v) if isinstance(v, list) else v
    if isinstance(saved, dict):
        for k, v in saved.items():
            if k in PER_FAN and not per_fan_ok(v):
                continue
            if isinstance(v, float) and not finite(v):
                continue
            if k in cfg and type(v) == type(cfg[k]):
                cfg[k] = v
            elif k in cfg and isinstance(cfg[k], float) and isinstance(v, int):
                cfg[k] = float(v)
    if check_curve(cfg["curve"]):
        cfg["curve"] = [list(p) for p in DEFAULTS["curve"]]
    return cfg


def check_curve(points):
    """None if the curve is usable, otherwise the reason."""
    if not isinstance(points, list) or len(points) < 2:
        return "need at least 2 points"
    last = None
    for p in points:
        if not isinstance(p, list) or len(p) != 2:
            return "point must be t:p"
        t, d = p
        if not (finite(t) and finite(d)):
            return "point must be numbers"
        if not (0 <= d <= 100):
            return "duty must be 0..100"
        if last is not None and t <= last:
            return "temperatures must rise"
        last = t
    return None


def curve_duty(points, t):
    if t <= points[0][0]:
        return float(points[0][1])
    for i in range(1, len(points)):
        t0, d0 = points[i - 1]
        t1, d1 = points[i]
        if t <= t1:
            return d0 + (d1 - d0) * (t - t0) / (t1 - t0)
    return 100.0  # above the last point: full speed, whatever the last duty says


def clamp(v, lo, hi):
    return lo if v < lo else hi if v > hi else v


class Controller:
    def __init__(self, cfg=None, now_ms=0):
        self.cfg = merge_config(cfg)
        self.boot_ms = now_ms
        self.last_ms = now_ms
        self.cpu = None          # last CPU temperature from the host
        self.cpu_ms = None       # when it came
        self.t_eff = None        # CPU temperature after hysteresis
        self.rest = False        # BYE received
        self.mode = "start"
        self.manual = [None] * NFANS
        self.duty = [float(self.cfg["start_duty"])] * NFANS
        self.target = list(self.duty)
        self.rpm = [0] * NFANS
        self.amb = None
        self.amb_level = 0       # 0 normal, 1 above amb_warn, 2 above amb_crit
        self.fault = False
        self.stall_since = [None] * NFANS
        self.stalled = [False] * NFANS
        self.flags = {}          # alarm name -> active
        self.save_requested = False
        self.service_requested = False
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

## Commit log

2026-09-23 FanCtrl3 1.0.0 - first complete design
    USB-powered controller for three 4-pin PWM fans, driven by the CPU
    temperature of a Proxmox VE host. The fan curve runs in the controller.
    - Pro: 2-layer PCB for hand soldering (TPS2553 limiter, LM27313 boost,
    2N7002 outputs); ERC 0, DRC 0, schematic parity 0; Gerbers and BOM.
    - Lite: the same circuit from modules on a PC-3 perfboard, generated
    layout, wiring drawing and wiring table; ERC 0.
    - Parametric OpenSCAD enclosure for both variants with a collision check.
    - MicroPython firmware and the fanctl host daemon for Proxmox VE.
    - Tests without hardware: control logic, firmware smoke test, end-to-end
    test of the host side against a simulated cont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
    [FanCtrl3-Lite.kicad_sch, FanCtrl3-Pro-BOM.csv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]
2026-09-23 Fix SERVICE: reset into service mode instead of dropping to the REPL
    The RP2040 watchdog cannot be stopped once it runs, so after SERVICE the
    board reset about 8 s later and mpremote lost it. SERVICE now leaves a
    flag file and resets; the next boot removes the flag, keeps the fans at
    100 % and stays at the REPL without starting the watchdog, until the
    next reset.
    - firmware: service_boot(), config and flag files relative to the root
    - tests: test_main_service.sh; run_all.sh stops at the first failure
    - docs: service access, protocol table
    Version 1.0.1.
    [logic.py, main.py]
2026-09-23 Fix STATUS right after BYE: report rest at once
    STATUS kept reporting the previous mode until the next control step.
    BYE now sets the reported mode to rest immediately, the same way TEMP
    sets auto; the fans still follow at the next step.
    Version 1.0.2.
    [logic.py]
2026-09-23 Fix fans stuck at rest duty after a daemon restart without temperature
    BYE puts the controller in rest mode, which has no timeout. A daemon that
    was restarted on a host without a readable CPU temperature never sent a
    TEMP, so the fans stayed at 20 % for good. New command HELLO: the daemon
    sends it on every connect; the controller leaves rest, forgets the last
    temperature and restarts the stale timer, so it ends in failsafe unless a
    TEMP follows.
    - firmware: HELLO in logic.py (unit test)
    - host: fanctl daemon sends HELLO after VER (end-to-end test)
    - docs: modes, protocol, daemon behaviour
    Version 1.0.3.
    [logic.py]
2026-09-23 Fix ambient alarms: one message per level change, 1 °C hysteresis
    Falling from the critical to the warning level sent INFO AMB OK followed
    by ALARM AMB HIGH, and falling from the warning level to normal sent
    nothing. The ambient temperature now has one level (normal, warning,
    critical) with a 1.0 °C hysteresis (new setting amb_hyst); every change
    of level sends exactly one line, and a reading that hovers around a
    threshold no longer makes the fans and the alarms flap.
    Version 1.0.4.
    [logic.py]
2026-09-23 Fix crash on a saved config with per-fan lists of the wrong length
    A saved min_duty or enabled with the wrong number of entries (or with
    non-numeric entries) was accepted by merge_config and crashed the control
    step. Such values are now ignored and the default is kept.
    Version 1.0.5.
    [logic.py]
2026-09-23 Fix SAVE: reply only after the configuration is written
    SAVE replied OK SAVE before the file was written, so a failed write
    looked like a success and only showed up as ERR INTERNAL. The controller
    logic now only requests the write; main.py writes the file and replies
    OK SAVE, or ERR SAVE <reason> when the write fails. The simulator does
    the same.
    - tests: logic test; SAVE success and failure on the real main.py
    Version 1.0.6.
    [logic.py, main.py]
2026-09-23 Fix calibrate in failsafe and the SAVE after a calibration that measured nothing
    Without a running daemon the controller went to failsafe and forced every
    fan to 100 %, so calibrate waited 30 s per step and stored a wrong
    minimum. calibrate now refuses to start in failsafe and stops, keeping
    the old minimum, when the controller does not follow the requested duty.
    It also sends SAVE only when a new minimum was measured.
    - host: calibrate split into calibrate() and measure_lowest()
    - sim: state reports the number of saves
    - tests: dead fan (no SAVE), calibrate in failsafe (refused, nothing changed)
    Version 1.0.7.
    [logic.py]
2026-09-23 Docs: tested and untested, known issues, hobby project note
    README now lists what is verified without hardware, what is not tested
    yet and the known issues. README and CONTRIBUTING say that FanCtrl3 is a
    hobby project developed in spare time, so updates may not come often.
    Version 1.0.8.
    [logic.py]
2026-09-23 Docs: GitHub Sponsors
    .github/FUNDING.yml for the Sponsor button, a Sponsor badge and a
    "Support the project" section in the README.
    Version 1.0.9.
2026-10-05 Firmware: reject nan and inf in SET, MIN, CURVE and the saved config
    SET 1 nan was accepted: the fan duty became nan, STATUS failed and every
    control step raised in set_duty (ERR INTERNAL, fans at 100 %). CURVE nan:20
    passed check_curve the same way. Command arguments now go through number(),
    which rejects non-finite values (ERR ARGS), check_curve requires finite
    numbers, and merge_config drops non-finite floats from a saved file.
    Also fix the LED comment in main.py and bump the version to 1.1.0.
    [logic.py, main.py]
2026-10-05 Host: AMD sensors, several CPU packages, clearer CLI errors
    - cpu_temp reads coretemp (Package id N), k10temp and zenpower (Tdie, else
    Tctl) and takes the hottest package instead of the first coretemp device.
    The daemon logs the sensors it reads once, and again when they change.
    - serve_client times out on a socket client that sends nothing, so it can
    no longer stop the TEMP updates.
    - fanctl send: 'no reply from the controller' instead of None; a missing or
    inaccessible device is a one-line error instead of a traceback.
    - tests/test_host.py covers all of the above without a controller.
2026-10-05 Scripts in bash instead of zsh; tests on GitHub Actions; issue templates
    zsh is not installed by default on Debian or Proxmox. The conversion is
    mechanical (${0:A:h}, setopt pipefail, print -r, the (N) glob qualifier).
    run_all.sh also runs tests/test_host.py. The workflow runs run_all.sh on
    Ubuntu 24.04 with the distribution's MicroPython.

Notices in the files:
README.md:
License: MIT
